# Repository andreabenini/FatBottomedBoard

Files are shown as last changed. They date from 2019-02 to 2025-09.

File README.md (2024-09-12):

# FatBottomedBoard
_Ben's Custom Keyboard. Huge, large &amp; heavy board for everyday work._  
---
_"This is my definitive keyboard I'll use for my daily work"_. This phrase is pretty much the same
every keyboard builder reports and relates to her/his work. I spend most of my time in front of it and
as many others I'd like to customize few things. Project is nearly complete and the keyboard is
working fine but, as many other do, it's much more a work in progress and always improvable where new
features are constantly added. This is not a blog but just a repository where all stable features are
reported, released and shared to the public, hopefully you can contribute to it, pull request or add
features to the project as well.

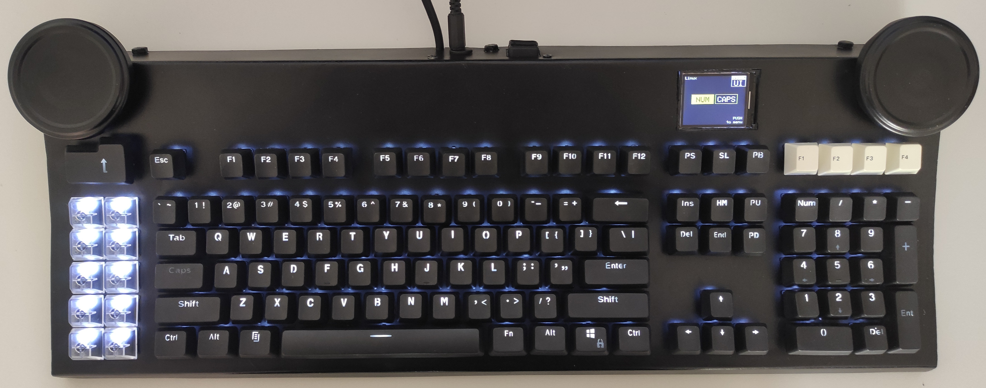
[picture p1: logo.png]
Keyboard overview


---
## Project featured on
- ### [hackaday.com](https://hackaday.com/2020/10/09/fat-bottomed-keebs-you-make-the-clackin-world-go-round/)
- ### [hackster.io](https://www.hackster.io/news/fatbottomedboard-is-a-massive-sun-type-5-style-mechanical-keyboard-for-serious-work-faa62c455731)
- ### [cyberreport.io](https://www.cyberreport.io/news/fat-bottomed-keebs-you-make-the-clackin-world-go-round?article=28913)

---
## Notes on the project
- _"This is my keyboard. There are many like it, but this one is mine."_ 
   ([Cit](https://en.wikipedia.org/wiki/Rifleman%27s_Creed)).
- As written on the name this is _not_ a reduced keyboard like a 60-75% or a compact one. It's a fat,
black, bad ass, heavy & huge board for a big desk, it's not portable and it's not the keyboard you
pickup in a bag with your laptop. It's the kind of keyboard you always leave on your desk with your
trusty mouse and big monitors
- _"I already had some parts lying around"_. Another recurring phrase, but it's true. I dismantled two
broken and acient AT/XT (with mechanical switches) keyboards I already had around and I discovered 
Cherry Black keys inside, it's a real pity to throw them away and that's why I've created this project.
Personal time and these keys (lockdown helped too...) are main factors for the project
- **It has to be cheap.** Cherry keys are quite expensive but with these already sourced parts I've
decided to create a really cheap project without breaking the bank. Approx cost is now ~40$ , even
lower if you already have Teensy boards (like me) and you'd like to manually build something on your
own
- **No special tools required.** I don't have access to 3D printers, CNC or PCB machines so I basically
built it everything from scratch. Manually. I'm not a coachbuilder and some particulars are really
rough, I'm aware of it, but it's my keyboard. If someone would donate me a cnc machined kbd frame
I would be really happy to change that.
- **no kits, it's not _just_ an assembly work. Manually build, assembly, adapt, paint.**
If you're looking for another instructables.com project with some sort of kit purchasable on Amazon
this is not the keyboard for you. Everything here starts from scratch. Leds, keys/keycaps, MCUs and
you manually need to build or add everything else.
[Hardware buildlog](hardware/buildlog/README.md) and each step is
pretty well documented, drop me a note for everything else.
- Full _Metal_. Frame comes from manually carved, drilled, sanded, bended and adapted piece
of 3mm stainless steel. Some paint, a drill, files, a Dremel, nut and bolts... and your time...
- **Sun Type 5 was the best layout ever**. I was a big Sun Microsystems fan before obscurantism and
I think Type5 layout is outstanding. I started the keyboard with that layout in mind and I've added
my personal touch and improvements to that.
---

## Project features
- 119 vintage cherry black keys (1984-1988 period)
- Two rotary encoders with push buttons
- LCD color display for user functions, configuration, builtin macros, games, num/caps, layout switch.
  Screen saver function if inactive after a certain period of time.
- Builtin 1Gb SD card for keeping special macros/combinations(/passwords?)
- Two Teensy++ 2.0 boards inside, serial communication between them, source code provided
    * One dedicated to the keyboard matrix only, no dead keys, 20 Cols x 6 Rows.
      [QMK](https://qmk.fm/) opensource firmware, hooks and custom actions
    * One dedicated to the remaining features: LCD, rotary encoders, SD KeyPass, special macros,
      backlight control, games, layout switch, external configuration
- External 5V power supply so you don't need to rely on poor 500mA from USB host side, common ground,
  full control on backlight (PWM without polling) and USB
- PWM led (white) backlight. NumLock and CapsLock are driven by your host, other keys are manually
  controlled with PWM. Several modes available: Normal / AlwaysON / AlwaysOFF / InverseLock
- Black & Transparent backlight keycaps set
- Builtin 4 port USB switch, two ports are internally used for the Teensy boards, two externally
  available for other devices (phones, headsets, ...). Power consumption depends on your external
  power supply, your're not tied to USB limitations
- US International layout on host side, internally switchable layouts (with a dedicated key) for all
non native english speakers. Starts with a EN-US layout (linux rules on that) but you can type latin
(or non latin) accented letters for your language.
Available layouts: UI: USA International EN-US/std, EN-US/int, IT/std.
Firmware extensible to any language
- Switchable OS (Linux: default, MacOS, Windows) [with a key combination] to enter special chars for
your favorite OS, no need to type unicode stuff (even if it remaps to it internally for some letters).
No keyboard drivers or special layouts are needed on the host side, just US-International on host side
- Two rotary encoders with push buttons. Customizable behavior. Now using: mouse scroll on right side,
password and macro keeper/scroller on left side. In setup mode right encoder is used to navigate menus.
- Builtin GAMES. Two rotary encoders and a small LCD screen ? Pong obviously ! More games coming btw..
  probably Arkanoid and other retro 80s games. There's a lot of space on Teensy++
- Special programs keys. Just like Type5 I prefer to have specific Cut/Copy/Paste keys and few more
  for most frequently used programs (need to map them on your OS)
    - Browser button, the big one below the left rotary encoder. Heavily used. (note: keycap from
    alternative bigass enter in the keyset)
    - Frequently used programs: Terminator, VisualStudioCode. Below browser button
    - Frequently used actions: Undo, Redo, Cut, Copy, Paste, Open, Close, Save
      in the left 10keys island
    - Gnome workspace desktop switch (1,2,3,4) for my taste, use whatever them you'd like.
      These are located below the right rotary encoder
- Play, Record, Custom macros with key combinations on each single key, courtesy of QMK firmware
- Ctrl,Alt,Super keys in this order. Just like MacOS cousins I really hate to have [SUPER] key between
  [Ctrl] and [Alt]. When I press in the middle I can send Ctrl+Alt or Ctrl+Shift+Alt with one finger.
- Special layout because I wanted it so (italian native here...). I don't like dead keys layouts and
  I want to use latin letters (è,é,ò,à,ù). Example: FN+E=è, RALT+E=é. So I still use standard us
  layout without worring too much. Same goes for € sign or other special chars as well.
  I prefer to keep US layout (which I love for sysadmin and programming) and enter additional chars
  from my language too when needed
- Large rotary encoder knobs. I want to use them from the side (just like DAS keyboards) or from the
  top (like a turn table). I did some video editing in the past and I still prefer large knobs. 
  _Those are not real knobs !_ They're just pot of jam lids filled with home made **Oogoo**. To me
  these are way better than traditional mouse wheels
- Software configurable from host side. With a python program you can upload a text file with
  custom macros to the keyboard SD card. With the left knob these macros are visible on the LCD
  display and selectable at will.
---

## Resources
- [BOM (Bill Of Materials)](BOM.md) available and up to date, links, costs and resources
- [Hardware buildlog](hardware/buildlog/README.md)
- Three basic sections
    - **[electronics](electronics)** Kicad schematics, pdf, lcd references and specs
    - **[hardware](hardware)** Frame schematics, credits, resource links and a photo buildlog. Everything is
    documented and photos are available to document the entire process
    - **[software](software)** keyboard (QMK with custom code) firmware and controller firmare (encoders, LCD,
    SD Card). Open source and available to everyone

## To Be Done
- Keycaps are still a work in progress (as every keyboard geek always says). Basic standard keyset
  is fine: looks cool, total black, custom backlight. But newly added keys in my 119 layout (+14
  transparent) are still a work in progress. I've bought transparent keys because
  I'd like to paint them black and carve from the internal to keep backlight led with some
  custom signs. 3D printing tests have not led to the expected results.
- Black paint from the inside and carve transparent keysets
- Transparent keys placed on upper right position (where F1-F4 keys were), need to take a new photo.
- Newly added wood rotary knobs are working fine, need to take a new photo for them as well, see
  current progress in the [buildlog](hardware/buildlog/38.big.knob.jpg)
- Remove the Windows keycap with something else, I don't want it in my keyboard
- Add more games. Arkanoids, maybe Pacman and few more
- Audio capabilities to the Teensy (maybe). When you play Pacman is somewhat important :)
- Some login procedure or something to encrypt internal SD card content, I'm now using it to play
  some macros but I'd like to store passwords as well
---

## Contact me
Mail me, clone the project (but give credits), git pull request and improve the software in any way.
I'm available for consulting or just for sharing ideas with you. Links in my github profile as usual.
I really wish to improve the hardware part as well. A contribution but even few 3D printed parts are
well accepted

<br/><br/><br/>
_Have Fun_  
_Ben_

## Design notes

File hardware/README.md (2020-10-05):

Hardware designs & layouts

---
**Note**
- keyboard-frame.png and poster-*.png files are just the temp result of keyboard-frame.eps, the could safely removed from here if needed
- **posterize.sh** splits `keyboard-frame.png` in pieces (`poster-*.png`) so they can be safely printed with 1:1 scale on common A4/US_Letter sheets
- QMK keyboard firmware builder is way better than TMK counterpart, use it to define wirings and create C defines
  and `KEYMAP()` proper mappings. Later on you might adapt generated code to TMK firmware. Just take a look at
  `kb.h` and `kb.c` generated files.
  **fatbottomedboard.json** was generated from https://kbfirmware.com/, you might use it again and return
  to that site to load configuration and alter it if needed.
  **keyboard-layout.json** was generated from http://www.keyboard-layout-editor.com/, you might use it again and return
  to that site to load configuration and alter it if needed.
  **keyboard-layout.[png|svg]** were generated from http://www.keyboard-layout-editor.com/ along with the json file

**Links**
- Layout editor  
  http://www.keyboard-layout-editor.com/
- Plate & Case builder  
  http://builder.swillkb.com/
- QMK Keyboard firmware builder https://kbfirmware.com/  
- Best guide *ever*, tons of suggestions in the entire process  
  https://www.reddit.com/r/MechanicalKeyboards/comments/4l0p41/guide_detailed_guide_to_making_a_custom_keyboard
- Building a keyboard from scratch (good general intro)  
  https://www.geekabit.nl/projects/building-a-keyboard-from-scratch/
- DIY keyboard collection (or how I became a KB-geek...)  
  nice case mods https://deskthority.net/viewtopic.php?f=7&t=2534&start=
- Firmware from TMK project  
  https://github.com/andreabenini/tmk_keyboard
- How to make a keyboard - The Matrix  
  powerful intro and good electrical documentation for a custom built diy keyboard, not just a ready made kit  
  http://blog.komar.be/how-to-make-a-keyboard-the-matrix/
- Brownfox keyboard, custom made keyboard, steel frame is the only thing maded outside this project  
  https://deskthority.net/viewtopic.php?f=7&t=6050&start=
- Custom made keyboard https://imgur.com/gallery/ba3jK (http://kbfirmware.com/)
- HackADay keyboard's bible  
  https://hackaday.com/tag/keyboard/
- Well explained on each single aspetct (hardware, electronics, software)  
  https://www.facebook.com/notes/wez-furlong/building-a-keyboard/10154070897701787/
- Lots of tips and tricks from this guy  
  https://matt3o.com/
- 3D printing resources  
  https://www.reddit.com/r/MechanicalKeyboards/wiki/3dprinting
- Key modifications  
  https://www.reddit.com/r/MechanicalKeyboards/wiki/key_modifications
- DIY resources from geekhack  
  https://geekhack.org/index.php?topic=69582.0
- Minimal Animal Keyboard  
  This guy did a really good job with its creation, just take a look at **imgur** to see it.  
  I'm also considering his important notes related to backlight  
  https://deskthority.net/viewtopic.php?f=7&t=7615&start=  
  https://deskthority.net/viewtopic.php?f=7&t=7779&start=  
  https://imgur.com/a/sWuH1

**Stabilizers**
- Cherry stabilizers mounting (under the plate)  
  https://www.youtube.com/watch?v=a173Blgfmww
- How To Assemble Cherry PCB Mount Stabilizers  
  https://www.youtube.com/watch?v=u-HYNmtP1Hc
- Cherry plate mounted stabilizers [7u,6.25u,2u]. Cheapest price found, they seems to be quite decent clones, don't know about the quality  
  https://www.aliexpress.com/item/32717878890.html

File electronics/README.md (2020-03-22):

# Keyboard schematics
All circuits have been created with _[Kicad](https://www.kicad-pcb.org/)_,
download and use it if you want to see `.sch` files

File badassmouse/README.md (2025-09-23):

# BadAssMouse (BAM!)
Ben's custom made mouse.  
Thinked, engineered and built as a perfect companion for this awesome keyboard.
Huge footprint but light for fast movements, modeled for covering my right hand entirely.

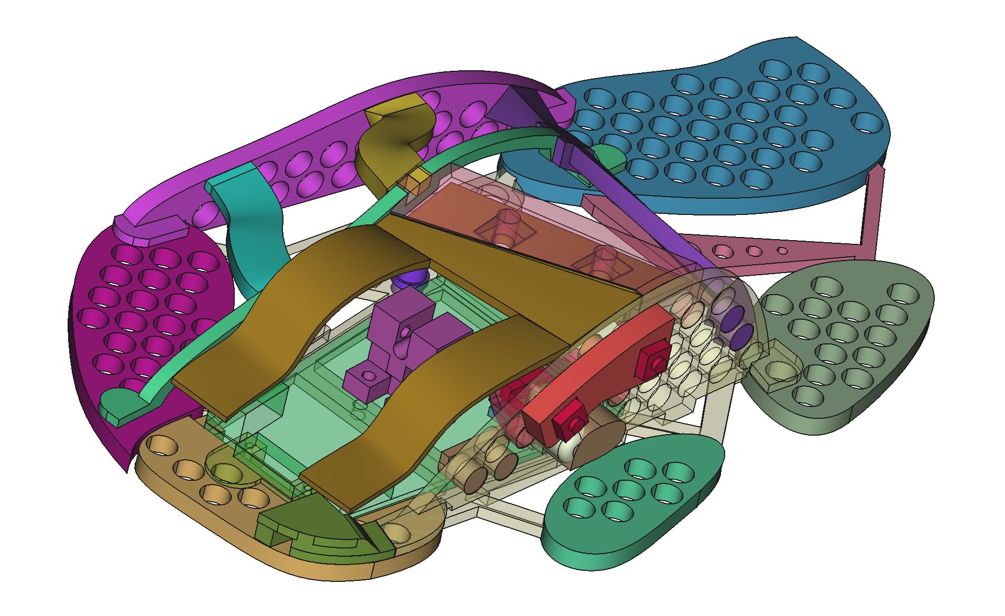
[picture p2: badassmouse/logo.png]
project logo


## Feature List
- lightweight and usable. It's a ~80g device where electronics and spin wheel are around 45g alone, so it's not the lightest mouse in the world as I've seen diy devices below 20g
  but considering consumer's grade devices usually weighting around 170g is not that bad.
- Lightweight & Usable Design: This mouse is engineered to be both lightweight and practical for everyday use
- Ultra-Low Friction Glide  
  Experience a near-frictionless glide thanks to a unique raised design that minimizes surface contact
  - **Minimal Contact:** The mouse body is elevated approximately **3mm** off the desk surface, preventing the main shell from creating any drag
  - **Pinpoint Precision:** It touches the desk on only **very few strategically placed points**, with each contact point having a tiny surface area of just **1 square millimeter**
  - **Built to Last:** Constructed from durable ABS plastic, the frame is reinforced with **4mm thick pillars**. This robust design is the primary reason for its weight,
    but it also guarantees a solid, flex-free body that can withstand heavy use
  - **Effortless Movement:** This design and overall weight drastically reduces friction, allowing the mouse to move with minimal effort and maximum speed, feeling almost as if
   it's floating around
- Reliable, Recycled Internals  
The core of this mouse is built upon proven technology, giving it a reliable and high-performance foundation
  - **Logitech Heart:** The main PCB and all essential electronic components have been carefully transplanted from a classic **Logitech M500** laser mouse
  - **Proven Performance:** This approach leverages the quality and reliability of Logitech's sensor and engineering, ensuring excellent tracking and button response without reinventing the wheel
- Hyper-Fast 'Infinity' Scroll  
One of the most celebrated features of the donor Logitech M500 has been fully integrated into this build: the hyper-fast, dual-mode scroll wheel
  - **Effortless Navigation:** The scroll wheel can be toggled into a free-spinning "infinity" mode. With a single flick, you can coast through thousands of lines in documents, spreadsheets, or web pages instantly
  - **Dual-Mode Precision:** The mouse retains the ability to switch back to a standard, tactile "click-to-click" mode for when precision and line-by-line control are needed
  - **A Signature Feature:** This powerful and satisfying function is a direct result of using the M500's internals, bringing a premium, productivity-enhancing feature to a unique custom body
- Dedicated Thumb Button (Middle Click)  
To improve ergonomics and functionality, a custom third mouse button has been added, accessible to the thumb
  - **Ergonomic Placement:** This new button is positioned laterally on the side of the mouse, offering a much more comfortable way to trigger a middle click without altering your grip
  - **Enhanced Functionality:** While the traditional middle click obtained by pressing the scroll wheel is still available, having a 
    **dedicated thumb button** is far superior for actions in 3D modeling software (GIMP, FreeCAD, Blender, Cura, ...)
  - **User Choice:** This design provides two distinct ways to perform a middle click, offering flexibility and a better user experience overall.
- Horizontal Tilt-Wheel Scrolling  
Another powerful feature inherited from the Logitech M500 internals is the tilt-wheel functionality
  - **Side-to-Side Scrolling:** The scroll wheel can be tilted left and right, providing seamless **horizontal scrolling**
  - **Productivity Boost:** This is incredibly useful for navigating wide spreadsheets, timelines in video editing software, or large images without having to use horizontal scroll bars
- Hyper-Personalized Ergonomics: Function Over Form  
Let's be honest: this mouse wasn't designed to win any beauty contests (it's ugly as hell)
  - **Custom-Molded Fit:** The external shell is unapologetically functional, sculpted specifically to the unique contours of **my** hand. It may look ugly as hell, 
    but every curve and indentation is intentional, designed for a perfect, strain-free grip
  - **Comfort is King:** While its looks are unconventional, the result is a level of comfort and control that mass-produced mice can't possibly match.
    It's built for endurance and a seamless connection between hand and cursor.
  - **Truly One of a Kind:** This is the core philosophy of the project. It's not just *a* mouse; it is quite literally **'my mouse'**. 
    The design is a unique expression of personal ergonomics, creating a tool that is perfectly tailored to its one and only user.
- Modular, LEGO-like Construction  
The entire mouse is designed with a modular, "LEGO-like" philosophy, allowing for endless iteration and customization
  - **Snap-Fit Assembly:** All the structural parts of the shell are designed to connect using precise snaps. This allows for rapid, tool-less assembly and disassembly 
    during the design and testing phases.
  -  **Iterative Design:** This system makes it incredibly easy to experiment with different shapes and component layouts. Once I'm happy with the form, a few drops of
    cyanoacrylate glue are used to make the connections permanent and rigid.
  - **Infinitely Reshapeable:** The core principle is flexibility. The mouse isn't a final, static object but a platform that can be easily broken down, modified, and
    rebuilt in a completely new form whenever desired.
- 3D Print Files and design available  
All the 3D models required to print your own version of this mouse are available in this repository
  - **Files Available:** You can find all the `.stl` design files ready for slicing in this directory
  - **Recommended Material:** ABS is highly recommended to match the sturdiness and durability of the original design. PLA can be used, but may be more brittle

## Pictures
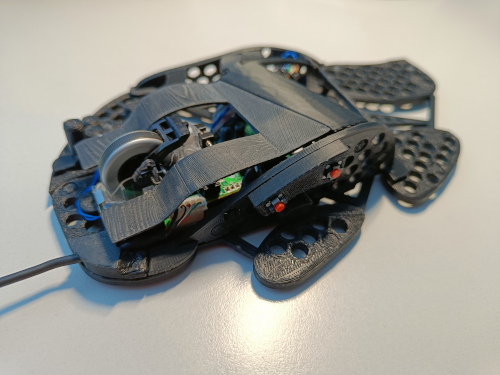
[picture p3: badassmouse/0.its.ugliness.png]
The guy, in real life
  
Its ugliness, in real life

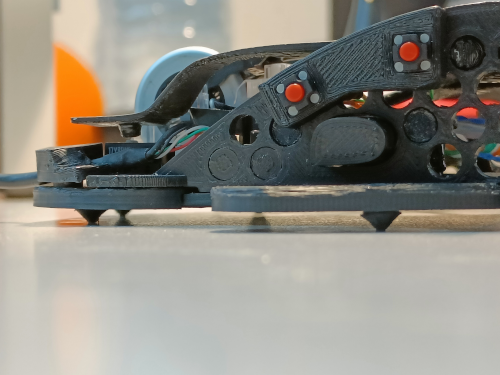
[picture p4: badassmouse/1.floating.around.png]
Floating in style
  
Floating on the desk

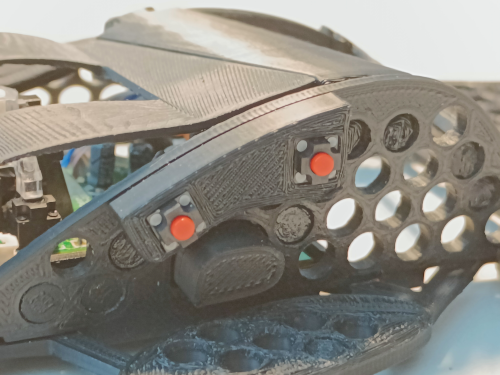
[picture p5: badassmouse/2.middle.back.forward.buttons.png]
Thumb button
  
middle/thumb button, back and forward buttons (silent switches, fast, low profile, low stroke)

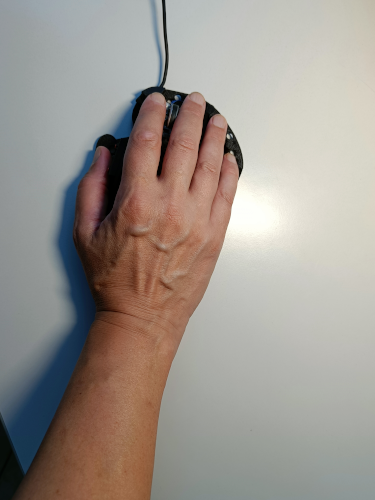
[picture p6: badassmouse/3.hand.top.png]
my mouse, my hand
  
Mouse covers the entire hand up to the wrist

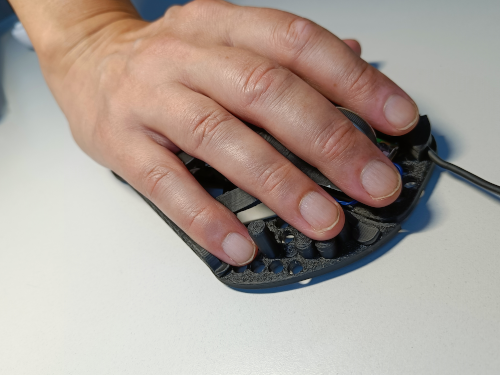
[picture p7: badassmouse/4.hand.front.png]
fingers view
  
Every finger is differently raised for ergonomics

## Support the Project
If you've enjoyed this project and would like to support its future development, thank you! Every little bit helps and is incredibly motivating
- **Fund the Next Version:** The dream is to create an even lighter and stronger V2 using **carbon fiber filament**. If you'd like to help make that a reality,
you can **buy me a spool of filament directly** or contribute towards the cost
- **Contribute Financially:** A small donation to help cover prototyping costs is always welcome. You can do so via [**PayPal**](paypal.me/bendonations)
- **Share the Project:** If you can't contribute financially, no problem at all! A star on the repository or giving project attribution when you share or use
the design is a fantastic and highly valued way to show your support

## Changelog

- **Revision 4**. Instead of modeling on a fully fledged mouse from internet this new version has been recreated
  totally from scratch and it's based on the shape of my hand only.    Weight and minimal points of contact with
  the surface are also key factors of this new design.  Electronics from M500 because I still have some of them.
- **Revision 3**. Cura sliced version, buttons in places, a lot of inner working on buttons thickness,
    internal palm support still in progress, external is fine but internal buttons shapes are not there yet.
- **Revision 2**. Lightly adapted print with better accomodations for the whole hand, fits well on my right hand
- **Revision 1**. First draft, 3d printed without buttons with overall shape to understand capabilities.

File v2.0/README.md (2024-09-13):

# V2.0
Build in progress, this will replace current version but at the moment it's still an experiment

- new project version is under construction
- Testing new CherryMX switches
- Testing new single key PCB
- BOM is defining while doing it
- No software (yet)
- No electronics (yet)
- 3d model not defined (yet)

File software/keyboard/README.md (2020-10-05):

# Firmware mod
Firmware for FatBottomedBoard

## Setup
#### Software installation
```sh
# or use your favorite package manager to get those packages
sudo pacman -S arm-none-eabi-gcc arm-none-eabi-newlib
```
#### Project setup
```sh
# cloning github project
git clone https://github.com/qmk/qmk_firmware
# Entering proper directory
cd qmk_firmware
# Creating submodule to start your own environment
make git-submodule
# Try to compile a basic example (optional)
make handwired/onekey/teensy_32:default
# Clean that basic example
make clean
```
#### Copy project configuration
```sh
# Add current configuration to qmk project
cd qmk_firmare/keyboards
ln -s ../../config/fatbottomedboard .
```

## Keyboard Manual
[This is up to date keyboard manual](manual.md) with keys, macros, layouts and current configuration.  
Complete keyboard layout is available in the [hardware section](../../hardware)

## Links 
- Hints on classics layouts http://www.quadibloc.com/comp/kyb0301.htm  
- QMK Keyboard firmware builder https://kbfirmware.com/  
- QMK Cheat sheet https://jayliu50.github.io/qmk-cheatsheet/
- List of unicode characters https://en.wikipedia.org/wiki/List_of_Unicode_characters

## Notes
QMK keyboard firmware builder is way better than TMK counterpart, use it to define wirings and create C defines
and `KEYMAP()` proper mappings. ~~Later on you might adapt generated code to TMK firmware.~~ Just take a look at
`kb.h` and `kb.c` generated files.  
**fatbottomedboard.json** was generated from https://kbfirmware.com/, you might use it again and return
to that site to load configuration and alter it if needed.  
[QMK](https://qmk.fm/) firmware was chosen for the project due to its cool features and good
documentation, reading docs and applying those features in a couple of hours is preferred to hacking
for weeks with an uncertain result and _(maybe)_ a 5% performance increase. **Even more:** user hooks
for custom code (here used for serial comm) with plain avr-gcc **C** code is awesome.

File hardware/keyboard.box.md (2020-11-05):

### FatBottomedBoard
# Keyboard Box
### Self locking box
|Dimensions|Internal|&nbsp;&nbsp;&nbsp;&nbsp;&nbsp;&nbsp;|External|
|---|--:|---|--:|
|_Length_|**55 cm**||**~68 cm**|
|_Width_ |**22 cm**||**~88.5 cm**|
|_Height_|**8.5 cm**||_paper ~0.4 cm_|

Keyboard width: 51.5 cm  
Knob ledge (each) ~1 cm (with 6.5cm knobs)  

Schematics  
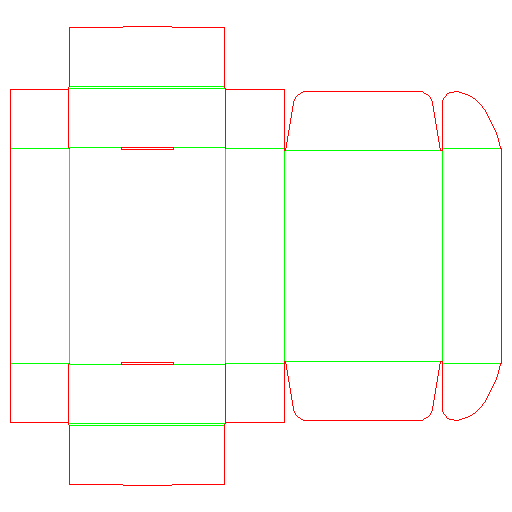
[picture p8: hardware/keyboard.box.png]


Box Preview  
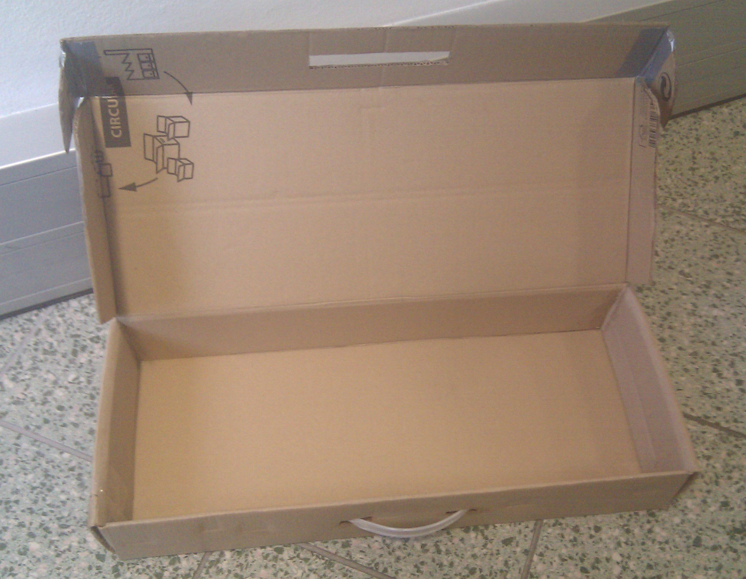
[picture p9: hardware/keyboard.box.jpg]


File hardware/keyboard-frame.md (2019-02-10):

# Settings
These are the settings for the frame builder (http://builder.swillkb.com/)

- Switch type: **MX {_t:1}**
- Stabilizer Type: **Cherry Only {_s:2}**
- Case Type: **Sandwich**
- USB cutout: **off**
- Mount holes: *8, 3, 10*
- Edge padding: **on (Top 35, Left 15, Right 15, Bottom 10)**
- Plate corners: **off**
- Custom Polygons: **on**
  * Rectangle (switch layer)
    - **width: 516, height: 40, centers: [0,-y-21], [0,0]**
  * Rectangle (switch layer)
    - **width: 516, height: 20, centers: [0,y+11], [0,0]**
- Kerf: **off**
- Key unit size: **off**
- Line color: **off**
- Line height: **off**

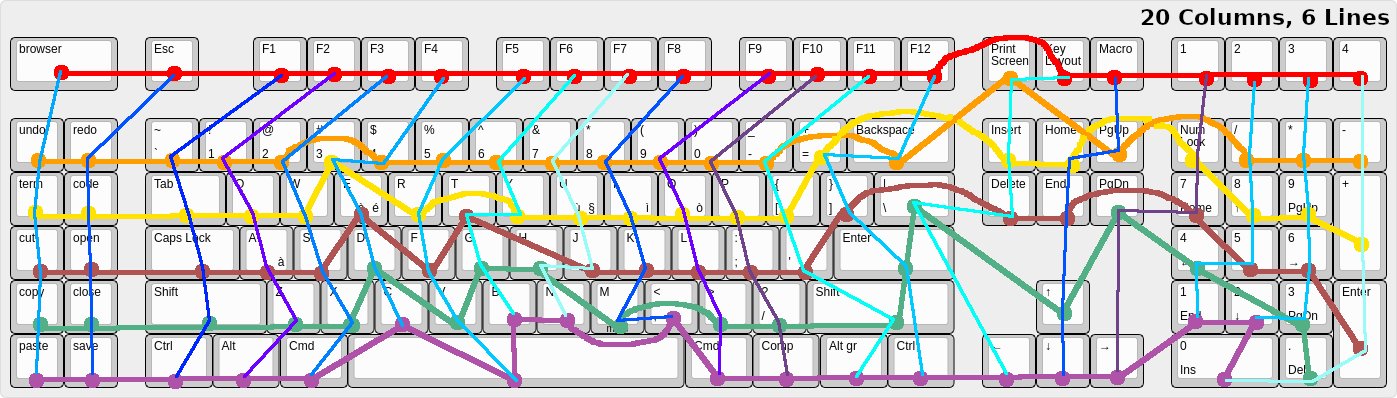
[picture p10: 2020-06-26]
hardware/keyboard-matrix.png

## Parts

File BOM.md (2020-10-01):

# Hardware
Buildlog and materials provided from the hardware section
- 50x50cm, 2mm stainless steel sheet. Got it from a surplus sale in a local hardware store. It's a poor quality and 2nd choice
  material, thin coated with cheap black paint, poorly finished. The only thing I like of it is the stainless, 2mm is fine because
  is not too thin or thick, good enough for keys and stabs mounts. Coating has to be brushed or replaced with something else.
  Really cheap part from a surplus sale cost: 5.00 €
- DIY Oogoo. Used as a filler for the Keyboard sides. 35% Corn Starch (Maizena), 60% Transparent Silicone, 4% Neoprene glue, 1%
  Laser printer black toner (from an used cartridge). Basic recipe from
  [Instructables](https://www.instructables.com/id/How-To-Make-Your-Own-Sugru-Substitute/)
  but hardened with the Neoprene glue. Mix and apply it quickly before it dries.
- [Mechanical Keyboard Plate Mounted Stabilizers](
https://www.banggood.com/Mechanical-Keyboard-Plate-Mounted-Stabilizer-6_25u-Modifier-Key-Spacebar-For-104108Keys-p-1249526.html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
  )
  #2 items (for backup and tests), I'll use most of them due to my extended keyboard. #2 x 8.77$
- Black spray paint, matte black (**RAL 9005**).  Car Wax. I already had them but you can purchase these in your local hardware
  store easily.
- 119 Cherry Black switches. Got them for free after dismantling two acient AT/XT keyboards. These are vintage Cherry Black buttons 
  from the 80s. Donor keyboards were reporting 1988 as the production date so these are original Black keys from the 1984-88 period.
- PBT English Language 108 Keyscaps Keys for Cherry MX Mechanical Keyboard Key Cap Switches, black matte (because it's cool).
  These are fairly good keycaps even if the price is bottom low. Nothing fancy but price is good and quality seems fine, time will
  tell how long they'll last.
  Just got [these keycaps](https://www.aliexpress.com/item/32902062981.html?spm=a2g0s.9042311.0.0.2c404c4dDWLgtp) from Ali for only 9.99
  but there're even cheaper ones, pick up your favorite color or theme, I was looking for black keycaps with backlight capabilities.
- _(R4)_ 10Pcs Transparent ABS Keycaps Mechanical keyboard Keycaps Matte Backlit Keycaps For Cherry Switch. Standard keycaps set
  (104-108) does not cover my keyboard schema and I need something more to keep up with my 119 switches. I don't want to paint them
  externally or ruin the touch so I bought them for some tests, pretty cheap too (**~2$**) so I can make a lot of tries. If results
  are decent I can even buy R1..R4 keys to match current switches.  
  I've found these https://www.aliexpress.com/item/4000645380162.html?spm=a2g0s.9042311.0.0.1dc24c4dvSdjEP but other alternatives
  are accepted as well, drop me a note or few hints on this.

# Electronics
Schematics available in the same dir, materials required are listed below:
- #2 Teensy 2.0++ USB AVR Development Board. Builtin USB controller, 5V version, Arduino toolchain and software. Original or cloned
  versions are both fine, price range on **5~10 €** from usual far east resellers, for example [this one](
      https://www.aliexpress.com/item/4000431099525.html?spm=a2g0s.9042311.0.0.5e3c4c4djyiYr1
  ) but there're cheaper alternatives on DX, Banggood and sites like that.  
  One for the controller, one for the keyboard firmware.
- 1.8" TFT display module, 128x160 8PIN TFT LCD, ST7735S Controller Drive 8/16 Bit SPI For Arduino Micro with SD.
  Ultra cheap and quite small head up like display for various keyboard functions, connected to the ATmega32U4 for
  custom configurations, password keeper and fancy setup. Easily available across the **2~3 €** price range, just like
  [this one](
      https://www.aliexpress.com/item/32906859151.html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
  )
- 119 1N4148 Diodes for the keys
- TIP112 NPN Darlington Transistor. 60V 2A. Because I already had it around but you can use whatever Darlington you've, better if it
  can handle more than 2A even if I won't use nominal 20mA on LEDs, they're really bright with just 10mA so this Darlington is fine
  as well.
- 1 1K&#8486; resistor for the Darlington base
- 117 470&#8486; resistors (backlight LEDs)
- 2 330&#8486; resistors (numlock and capslock leds), these are controlled directly from the Teensy++ not from the Darlington
- Spare resistors for the LCD display: 6x1K&#8486;, 1x330&#8486;, 1x100&#8486;
- Heat shrink tubing, wirings get complicated if you sum backlight wirings (one resistor, one key) and common keyboard matrix (one diode
  for each key). See buildlog for details.  You'd better insulate cables when you use your soldering iron. Alternatively you might use
  enameled wire but when you weld diodes you still have some tin to insulate

# Software
Everything is open source from this repository, no external deps required. You can pickup ready made _.hex_ binary files or compile them
on your own.  
Use GitHub pull requests, issues and comments here or on chat for your getting in touch.

&nbsp;
### NOTE
---
BOM defined contains all materials used for the making, prices are indicative and many components are not planned from scratch,
project is mainly based on what I've around.  
I can keep it cheap because it's based on already purchased materials. Project started because I've scavenged vintage cherry black
switches from old devices. Personal time and manual skills can keep the price low but this might cost you as well 
_(can you measure it ?)_

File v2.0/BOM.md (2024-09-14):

# Hardware
Buildlog and materials provided from the hardware section
- Mechanical Keyboard Plate Mounted Stabilizers, from version 1 of this project
- Black spray paint, matte black (**RAL 9005**).  Car Wax. I already had them but you can purchase them in your local hardware
  store easily.
- PBT English Language 108 Keyscaps Keys for Cherry MX Mechanical Keyboard keycap switches, black matte (because it's cool).
  Recycled them from version 1 of this project, original cost was around 9.99. There's no difference between standard Cherry keycaps
  and low profile ones, they usually fit well.
- _(R4)_ 10Pcs Transparent ABS Keycaps Mechanical keyboard Keycaps Matte Backlit Keycaps For Cherry Switch. Standard keycaps set
  (104-108) does not cover my keyboard schema and I need something more to keep up with my 120 switches. I don't want to paint them
  externally or ruin the touch. mostly recycled from version 1 too.

# Electronics
Schematics available in the same dir, materials required are listed below:
- MxLEDBit Single Switch PCB, MX/Choc/Hot Swap Socket, Cherry MX version, Led ready, 4x25pcs, ~4.90E. (each).
  That's my biggest departure from my previous fully handmade wired project, these boards are a timesaver, handy, thin, cheap and
  provide better results. They also save you a huge amount of time while wiring. 1U Amoeba pcb boards are totally fine but this one
  is cheaper to purchase in the EU (no customs). You can get discounts and a competitive price from usual PCB manufacturers even if
  it seems to be the best bet for my money here. They can perfectly fit with all Cherry MX switches including low profile ones.  
  [Single Switch PCB](https://keycapsss.com/keyboard-parts/pcbs/173/mxledbit-single-switch-pcb-mx-choc-hot-swap-socket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)
- Original Cherry MX low profile rgb Red Switch, 120pcs, ~50E. (various discounts might apply based on the season).  
  This is obviously where most of the budget goes, discount and various prices might apply and if you have a cheaper alternative
  open an issue or let me know as a comment.  
  Before starting the flame on MX flavors I'd like to report I'm a heavy hitter and always been a cherry black fan. I also used
  cherry brown for a while but these low profiles are amazing and I finally decided to use Reds, on low profile ones the bump on
  brown does not really makes any sense to me.  
  [Original Cherry MX low profile RED](https://www.aliexpress.com/item/1005007533369880.html?spm=a2g0o.order_list.order_list_main.15.46df1802PQbq6Z)
- SMD diode, 1N4148W, SOD123 package, 2x100pcs, ~2.50E (from timely aliexpress discounts).  
  Common 1n4148 are fine too, In my case I've decided to use the SOD123 package to minimize space, through hole diodes are good as well.  
  [1N4148 Diodes](https://www.aliexpress.com/item/1005005707644429.html?spm=a2g0o.order_list.order_list_main.10.46df1802PQbq6Z)
- GTBL SK6812 SMD MINI-E RGB LED Chip Individually Addressable Full Color DC 5V, 2x100pcs, ~7.20E. (discounted in a sale on AliExpress).
  These are optional, I have plenty of high intensity 3mm white leds and there's no need to purchase these SMDs if you are considering
  manually wiring. BTW these are thinner and they perfectly fit inside low profile cherry mx switches. They are inexpensive and
  a nicely added value if you are considering a low profile layout.  
  [SK6812 SMD RGB Leds](https://www.aliexpress.com/item/1005003056797785.html?spm=a2g0o.order_list.order_list_main.5.46df1802PQbq6Z)
- Teensy 2.0++ USB AVR Development Board. Builtin USB controller, 5V version, Arduino toolchain and software. Originals or cloned
  versions are both fine, price range from usual far east resellers. This comes free from version 1 of this project. I'm using
  teensy 2++ because they provide a lot of inputs for a huge matrix like mine (120 keys). QMK keyboard firmware with some special
  mods to support my fancy remapping and add communication features to exchange data between these two MCUs

#### To be defined
    - 1.8" TFT display module, 128x160 8PIN TFT LCD, ST7735S Controller Drive 8/16 Bit SPI For Arduino Micro with SD.
      Ultra cheap and quite small head up like display for various keyboard functions, connected to the ATmega32U4 for
      custom configurations, password keeper and fancy setup. Easily available across the **2~3 €** price range
    - 1 1K&#8486; resistor for the Darlington base
    - Spare resistors for the LCD display: 6x1K&#8486;, 1x330&#8486;, 1x100&#8486;
    - Heat shrink tubing, you'd better insulate cables when you use your soldering iron

# Software
Everything is open source from this repository, no external deps required. You can pickup ready made _.hex_ binary files or compile them
on your own. Use GitHub pull requests, issues and comments here or on chat for your getting in touch.

&nbsp;
### NOTE
---
BOM defined contains all materials used for the making, prices are indicative and many components were not planned from scratch,
project is mainly based on what I've around.

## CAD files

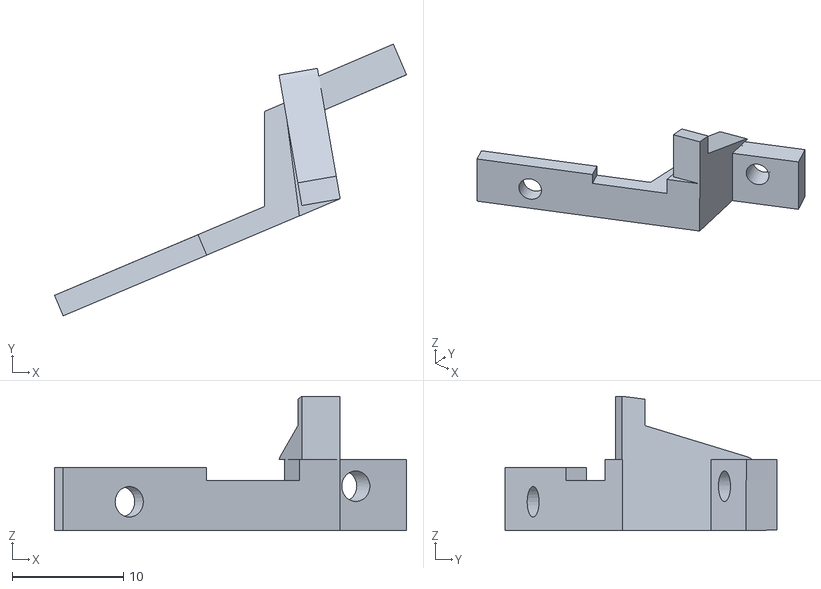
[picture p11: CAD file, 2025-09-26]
badassmouse/bam-underbridge blocker.stl
31.6 x 24.4 x 12.1

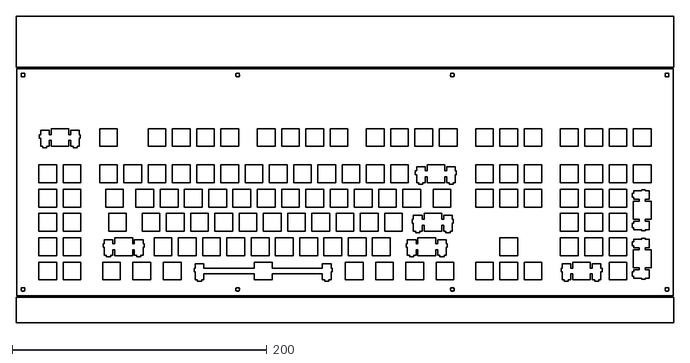
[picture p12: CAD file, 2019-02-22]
hardware/keyboard-frame.dxf
516.0 x 240.4

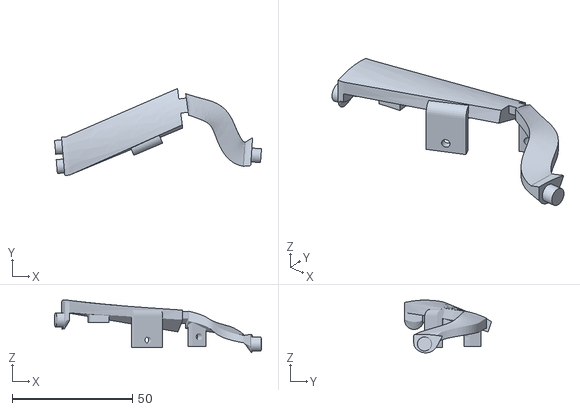
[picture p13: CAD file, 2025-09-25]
badassmouse/bam-partition pinky right 2.stl
86.1 x 36.2 x 21.9

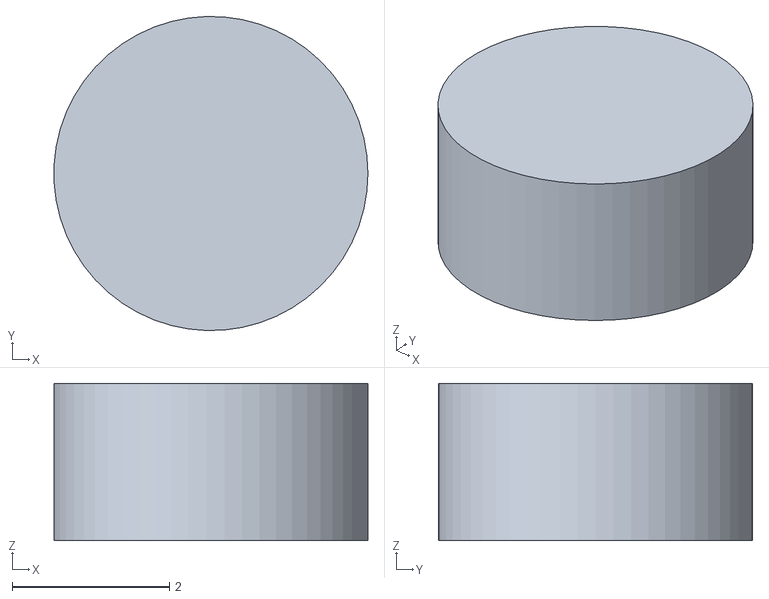
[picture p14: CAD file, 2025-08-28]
badassmouse/bam-mouse button thickness.stl
4.00 x 4.00 x 2.00

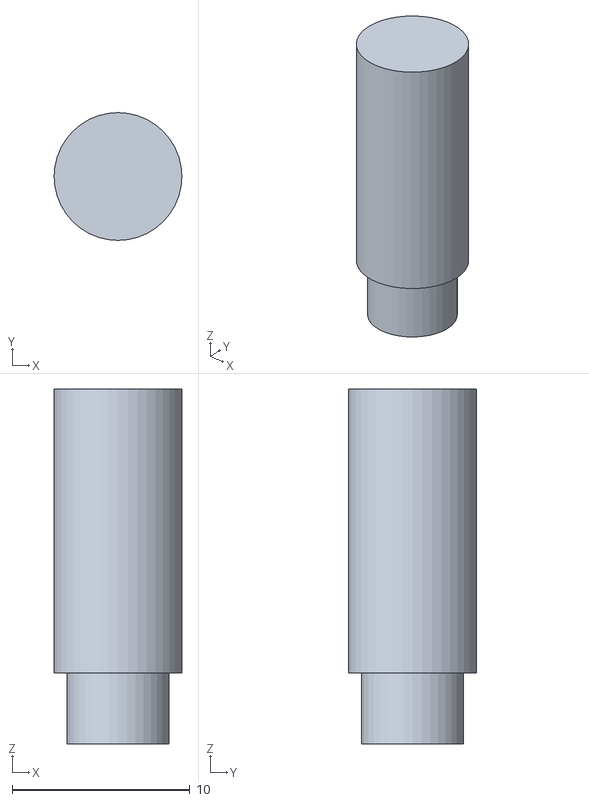
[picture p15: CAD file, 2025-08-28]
badassmouse/bam-Ring holder top.stl
7.20 x 7.20 x 20.0

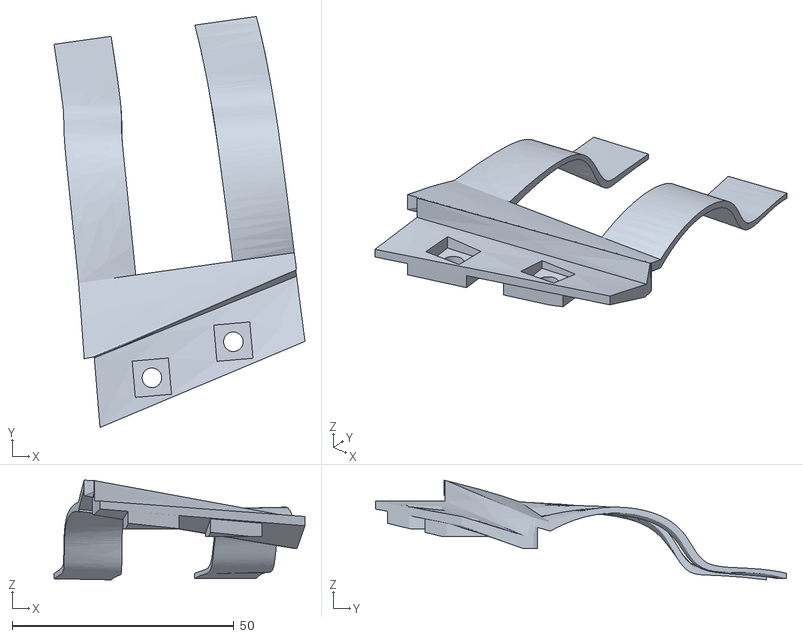
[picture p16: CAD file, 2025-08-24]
badassmouse/bam-mouse buttons.stl
56.6 x 92.6 x 22.5

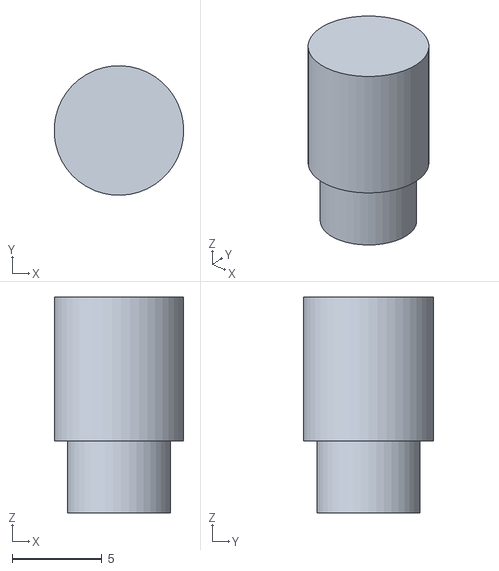
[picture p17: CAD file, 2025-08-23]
badassmouse/bam-Ring holder.stl
7.19 x 7.20 x 12.0

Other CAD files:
electronics/SKU676781/51 test procedure/Comprehensive test (requires more than 16K ROM microcontroller)/Comprehensive test (requires more than 16K ROM microcontroller)/main.OBJ
electronics/SKU676781/51 test procedure/Basic brush test/main.OBJ
electronics/SKU676781/51 test procedure/Basic brush test/touch.obj
electronics/SKU676781/51 test procedure/Comprehensive test (requires more than 16K ROM microcontroller)/Comprehensive test (requires more than 16K ROM microcontroller)/font.obj
electronics/SKU676781/51 test procedure/Basic brush test/LCD.obj
electronics/SKU676781/51 test procedure/Comprehensive test (requires more than 16K ROM microcontroller)/Comprehensive test (requires more than 16K ROM microcontroller)/sys.obj
electronics/SKU676781/51 test procedure/Basic brush test/font.obj
electronics/SKU676781/51 test procedure/Basic brush test/STARTUP.OBJ
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

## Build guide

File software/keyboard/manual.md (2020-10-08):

# Keyboard manual _(BABE)_

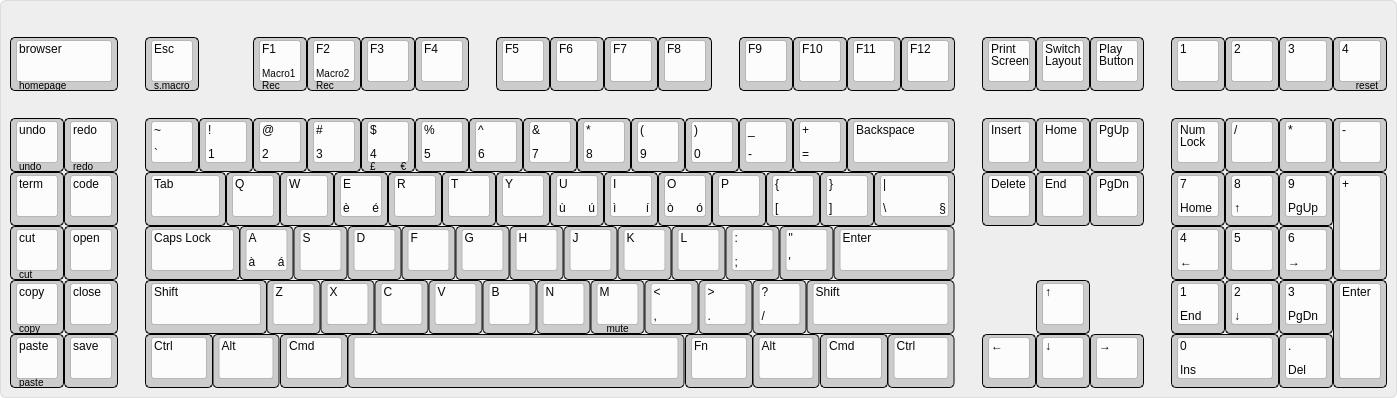
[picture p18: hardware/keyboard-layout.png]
Keyboard layout

Here you can see the complete keyboard with silk-screen keys

---

## Host configuration

Just _one_ simple rule: **SELECT US-English Keyboard Layout. That's it, no more, no less.**  

There's no need to use US-International, language packs or additional layouts on the host side.  
Each operating system has its own ways to enter latin characters (á,é,í,ó,ú, ...), I've tried to
skip dead keys layout, US International sounds cool but it's a mess if you'd like to enter ',",`,...
Windows particularly sucks on this aspect and many users created
special keyboard layouts to override US-Intl behavior with dead keys, there's no need for that.

## Special inputs characters
| Combination | Result | Example or Notes|
|- |- |-|
| _Special Characters_ |||
| **\<FN>**+**_\<letter>_** | [**`**] Grave accent letter | FN+e = è |
| **\<ALT>**+**_\<letter>_** | [**´**] Acute accent letter | ALT+e = é |
| **\<ALT>**+**_<4>_** | [**€**] Euro sign | _where **$** sign is reported_ |
| **\<FN>**+**_<4>_** | [**£**] Pount sign | _where **$** sign is reported_ |
| **\<FN>+\<\\>** | § | § |
| _Editing Functions_ |||
| **\<UNDO>** | Ctrl+Z | Generic undo key |
| **\<REDO>** | Ctrl+Y | Redo with Ctrl+Y (vscode) |
| **\<FN>+\<REDO>** | Ctrl+Shift+Z | Redo with Ctrl+Shift+Z (eclipse) |
| **\<CUT>** | \<Ctrl>+\<X> | Cut |
| **\<FN>+\<CUT>** | \<Shift>+\<Del> | _cut_  _(classic)_|
| **\<COPY>** | \<Ctrl>+\<C> | Copy |
| **\<FN>+\<COPY>** | \<Ctrl>+\<Insert> | _copy_ _(classic)_|
| **\<PASTE>** | \<Ctrl>+\<V> | Paste |
| **\<FN>+\<PASTE>** | \<Shift>+\<Insert> | _paste_ _(classic)_|
| _OS Features_ |||
| **\<Browser>** | Start chrome browser | Mapped to LSFT(KC_F20) on OS  |
| **\<FN>+\<Browser>** | Browser Home (Windows) | _#define KC_WWW_HOME_  |
| **\<FN>+\<M>** | Volume mute | _#define KC__MUTE_ |
| **\<SwitchLayout>** | Toggle keyboard layouts | **EN**:US English, **IT**:Italian, **UI**:US International|
| **\<FN>+\<SwitchLayout>** | Toggle OS | Toggle OS (Linux, MacOS, Windows) |
| _Macro Functions_|||
| **\<PlayButton>** | Layer for macro input | Toggle layer for playing macros |
| **\<FN>+\<F1>** | Record MACRO1 | Start recording MACRO1 |
| **\<FN>+\<F2>** | Record MACRO2 | Start recording MACRO2 |
| **\<FN>+\<ESC>** | Stop recording macro | Stop recording previously started macro (if any)|
| **\<PlayButton>+\<F1>** | Play recorded MACRO1 | Execute recorded MACRO1 |
| **\<PlayButton>+\<F2>** | Play recorded MACRO2 | Execute recorded MACRO2 |
| _Firmware Functions_|||
| **\<FN>+\<WS4>** | Reset keyboard | boot loader for firmware upgrade |
**NOTES:**
- **MACRO1**, **MACRO2** can be created/modified at runtime but are volatile, they're lost when
keyboard is turned off

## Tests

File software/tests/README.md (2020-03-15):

All of the Pro Micro's I/O and power pins are broken out to two, parallel headers. 
Some pins are for power input or output, other pins are dedicated I/O pins. 
Further, the I/O pins can have special abilities, like analog input. 
Here's a map of which pin is where, and what special hardware functions it may have:

# Pro Micro Pinout
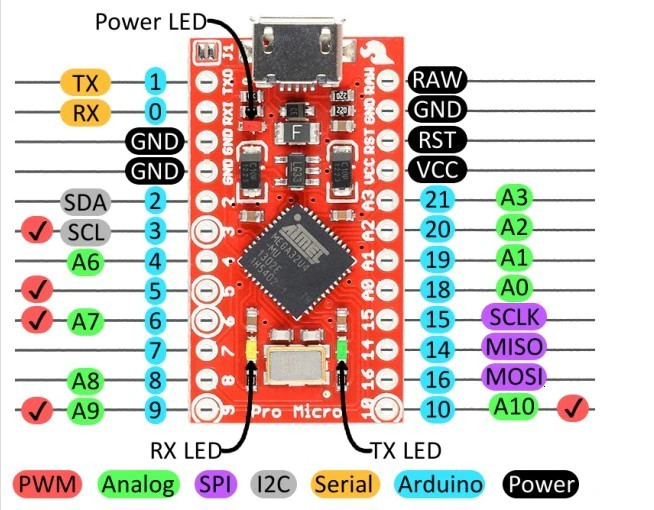
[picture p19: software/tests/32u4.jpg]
preview
  
Delving a little further into which pins do what...

## Power Pins
There are a variety of power and power-related nets broken out:

- RAW is the unregulated voltage input for the Pro Micro.
If the board is powered via USB, the voltage at this pin will be about 4.8V (USB's 5V minus a schottkey diode drop).
On the other hand, if the board is powered externally, through this pin, the applied voltage can be up to 12V.
- VCC is the voltage supplied to the on-board ATmega32U4.
This voltage will depend on whether you're using a 3.3V/8MHz Pro Micro or a 5V/16MHz version,
it'll be either 3.3V or 5V respectively. This voltage is regulated by the voltage applied to the RAW pin.
If the board is powered through the 'RAW' pin (or USB), this pin can be used as an output to supply other devices.
- RST can be used to restart the Pro Micro. This pin is pulled high by a 10kOhm; resistor on the board, 
and is active-low, so it must be connected to ground to initiate a reset. 
The Pro Micro will remain "off" until the reset line is pulled back to high.
- GND, of course, is the common, ground voltage (0V reference) for the system.

## I/O Pins
The Pro Micro's I/O pins -- 18 in all -- are multi-talented.
Every pin can be used as a digital input or output, for blinking LEDs or reading button presses.
These pins are referenced in the Arduino IDE via an integer value between 0 and 21.
(The A0-A3 pins can be referenced digitally using either their analog or digital pin number).

Nine pins feature analog to digital converters (ADCs) and can be used as analog inputs. 
These are useful for reading potentiometers or other analog devices using the analogRead([pin]) function.

There are five pins with pulse width modulation (PWM) functionality, 
which allows for a form of analog output using the analogWrite([pin], [value]) function. 
These pins are indicated on-board with a faint, white circle around them.

There are hardware UART (serial), I2C, and SPI pins available as well. 
These can be used to interface with digital devices like serial LCDs, XBees, IMUs, and other serial sensors.

The Pro Micro has five external interrupts, which allow you to instantly trigger a function when a 
pin goes either high or low (or both). If you attach an interrupt to an interrupt-enabled pin, you'll need 
to know the specific interrupt that pin triggers: pin 3 maps to interrupt 0 (INT0), pin 2 is interrupt 1 (INT1), 
pin 0 is interrupt 2 (INT2), pin 1 is interrupt 3 (INT3), and pin 7 is interrupt 4 (INT6).

## On-Board LEDs
There are three LEDs on the Pro Micro. One red LED indicates whether power is present.

The other two LEDs help indicate when data is transferring over USB. 
A yellow LED represents USB data coming into (RX) the the Pro Micro, 
and a green LED indicates USB data going out (TX).

## 3.3V or 5V? 8MHz or 16MHz?
Pro Micros come in two flavors, which vary by system voltage and operating frequency. 
The standard 5V Pro Micro runs at 16MHz, and is very comparable to an Arduino Leonardo, 
while the 3.3V version of the Pro Micro runs at half the speed 
(to remain in the safe operating zone at the lower voltage) -- 8MHz.

The operating voltage of your Pro Micro determines the maximum allowable voltage on any of the I/O pins.
For example, if you have a 3.3V Pro Micro, don't interface it with something that outputs 5V.

Don't forget which version you have! We'll need to differentiate between the two when we get to
uploading code in Arduino. If you're not sure which version you have, check the back corner of the board.
One of two boxes should be checked to indicate the operating voltage.

## How to Power the Pro Micro
As the Pro Micro's main feature is its innate USB functionality, the most common way to power it is via USB.
In this setup, a 5V Pro Micro will be powered directly from the USB bus and a 3.3V Pro Micro will regulate
the 5V supply coming in from USB down. The other end of the USB cable can be connected to either a computer,
USB hub, or a USB wall adapter, which can (in most cases) provide more power.

Alternatively, if your Pro Micro is living out in the wild, out of reach of USB cables, 
it can be powered through either the 'RAW' or 'VCC' pins. A supply going into the 'RAW' pin will be regulated 
down to the correct operating voltage (5V or 3.3V). To be safe, it shouldn't be any higher than 12V, and it 
should be at least 1V more than the Pro Micro's operating voltage (e.g. >6V for a 5V Pro Micro).

If you power the Pro Micro through the 'VCC' pin, keep in mind that this signal is unregulated.
Only use this if you have a clean, regulated 3.3V or 5V supply to connect to it.

How, exactly, you power your project is up to you and the demands of your project. 
If you're making something battery powered, you may want to opt for the 3.3V Pro Micro, which could be powered
by a LiPo battery or a couple alkalines.

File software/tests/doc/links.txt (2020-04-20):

LCD TFT Display
https://randomnerdtutorials.com/guide-to-1-8-tft-display-with-arduino/
https://www.hackster.io/electropeak/ultimate-beginner-s-guide-to-run-tft-lcd-displays-by-arduino-081006
https://electropeak.com/learn/absolute-beginners-guide-to-tft-lcd-displays-by-arduino/
http://acoptex.com/project/263/basics-project-054a-18-spi-tft-lcd-128x160-module-and-flickering-streaks-at-acoptexcom/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

Rotary Encoders
https://howtomechatronics.com/tutorials/arduino/rotary-encoder-works-use-arduino/
https://www.brainy-bits.com/arduino-rotary-encoder-ky-040/  (debouncing and inaccuracy sw fixes)

Buttons
https://create.arduino.cc/projecthub/muhammad-aqib/arduino-button-tutorial-using-arduino-digitalread-function-08adb5

Keyboard-Mouse
https://www.arduino.cc/en/Tutorial/KeyboardMessage
https://www.sparkfun.com/tutorials/337

Software [PC]
https://github.com/signal11/hidapi          [hidapi lib]
https://github.com/trezor/cython-hidapi     [Python import]

Software [Arduino]
https://github.com/NicoHood/HID             [Arduino HID project "HID-Project.h", (RawHID object)]

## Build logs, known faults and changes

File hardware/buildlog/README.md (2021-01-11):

# Build Log
This is a basic build log, it's not a blog yet but feel free to ask if you want additional
documentation or something more than just few steps and some photos. I've never published
a video for it so if you prefer to have something better just ask.  

Here are just basic steps and keyboard making in a long journey, I've worked on it in my spare time
and when cheap (or free) materials were available. This is just a basic photo doc.  

---

### It all started with a scrap piece of metal
With a cheap 2mm stainless steel sheet and my jig saw I've cut keyboard base plate, basic keyboard
shape has been created with classic http://www.keyboard-layout-editor.com/. All link and resources
are readily reported in this project as well
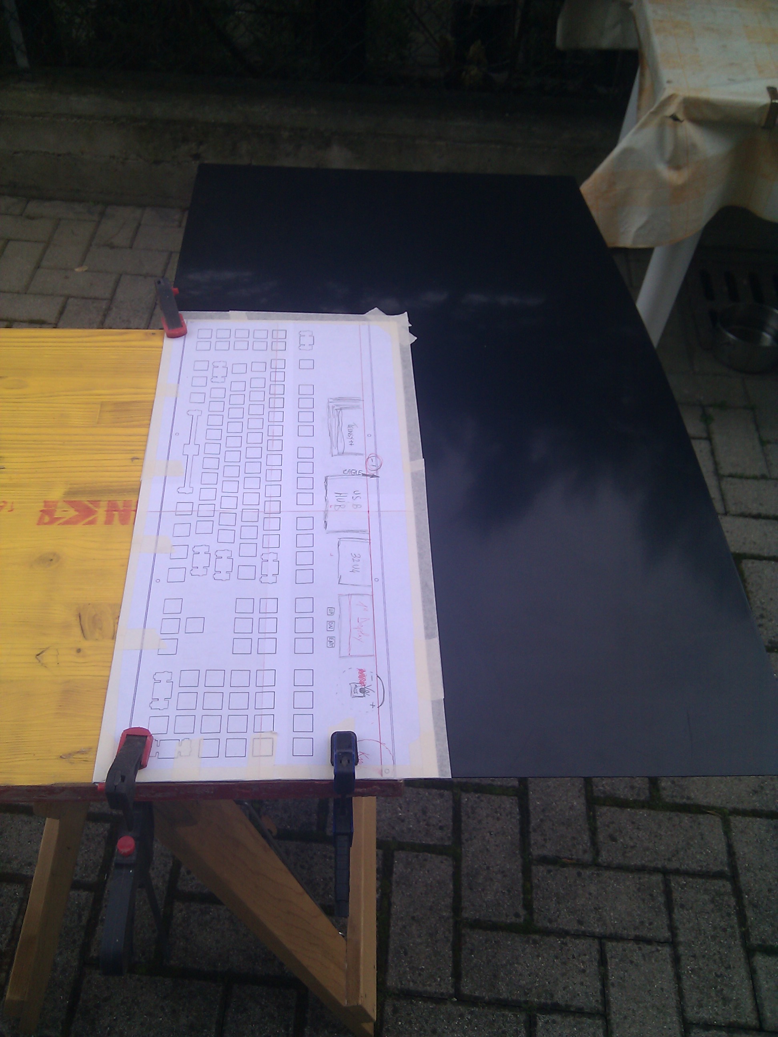
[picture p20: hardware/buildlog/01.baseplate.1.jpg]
metal foil


A basic cut and some sanding on the edges. With a drill I've placed holes where necessary and with a
cutter and my files I've shaped proper key housings. This is not a difficult operation, just a little
bit boring but it's still easy.
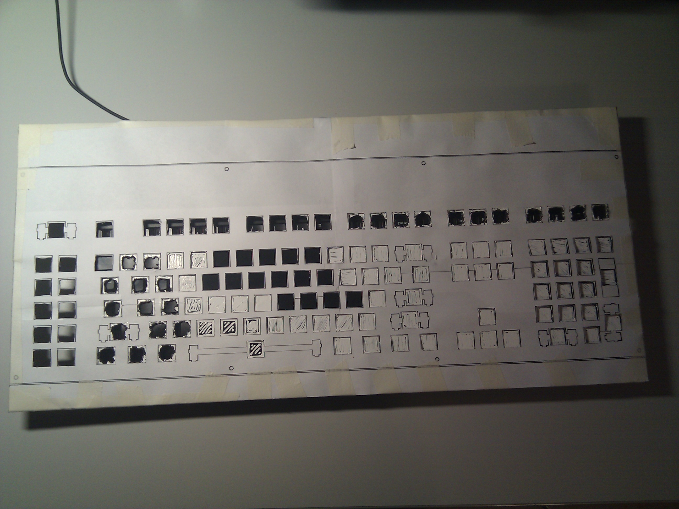
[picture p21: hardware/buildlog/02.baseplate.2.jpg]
drill,drill,drill


With a marker I've painted key housings, on the left there're few completed squares, in the
middle few of them are drilled, on the right a lot of work has to be done.
Still boring but quite easy too.
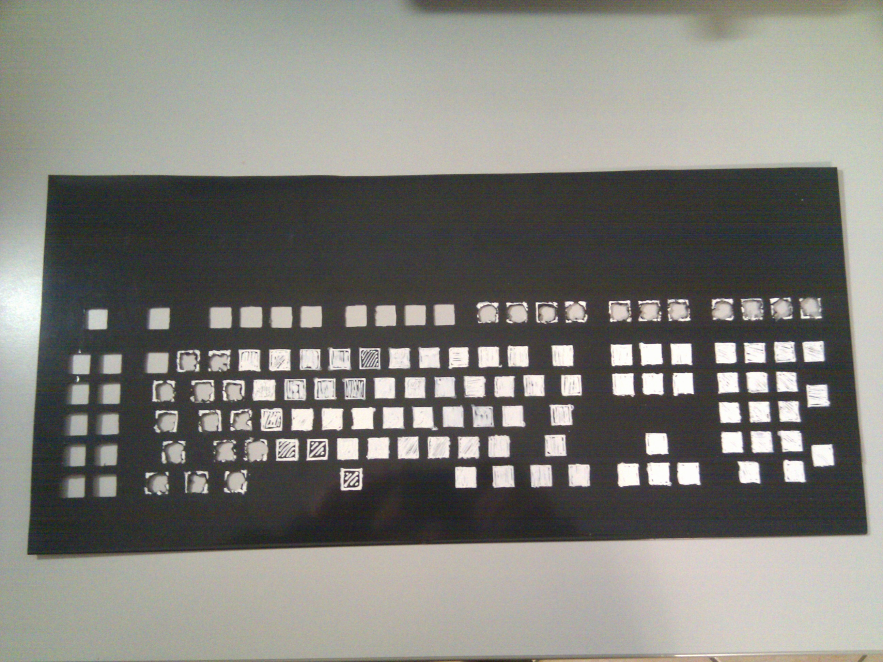
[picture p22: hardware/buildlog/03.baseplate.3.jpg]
still a lot of drilling


After a long while and a lot of repetitive job with small files I finally have some nice metal
artifact. If you're on the cheap and you don't want to waste money on CNC machining this is what you
can do, if you've some money and you can afford a professional work is up to you to get something
better. DXF, EPS and full specs are available
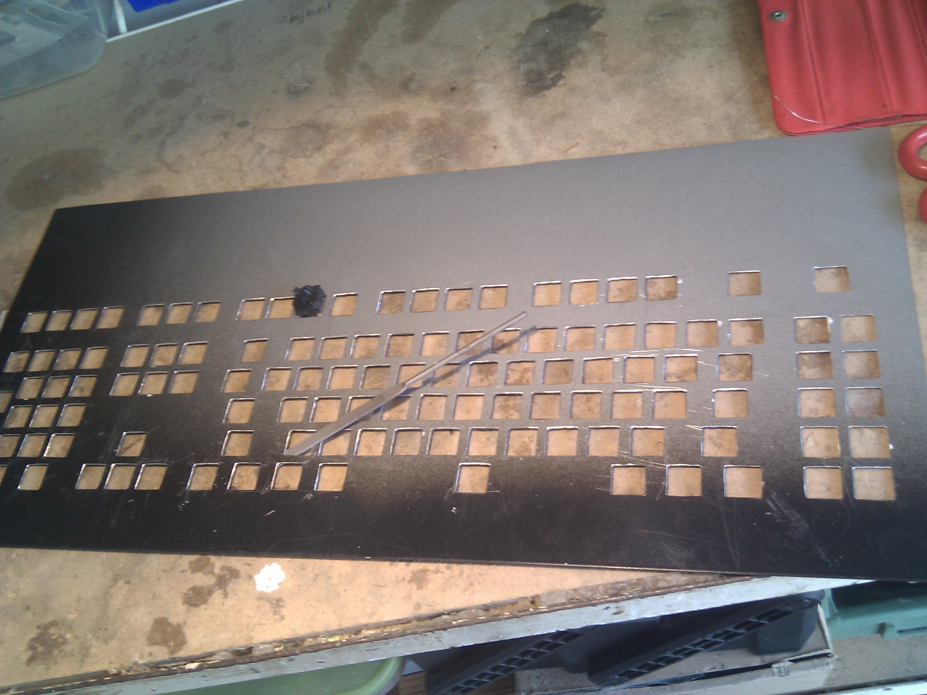
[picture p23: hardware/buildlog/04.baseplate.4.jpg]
nice metal sheet


After a lot of refining work with my files I've bended it with a squared steel bar. I've started
from the bottom in order to keep clean folds, I've avoided to use an hammer because I don't have
professional squaring tools. Take your time (and your patience), you cannot do a fold twice.
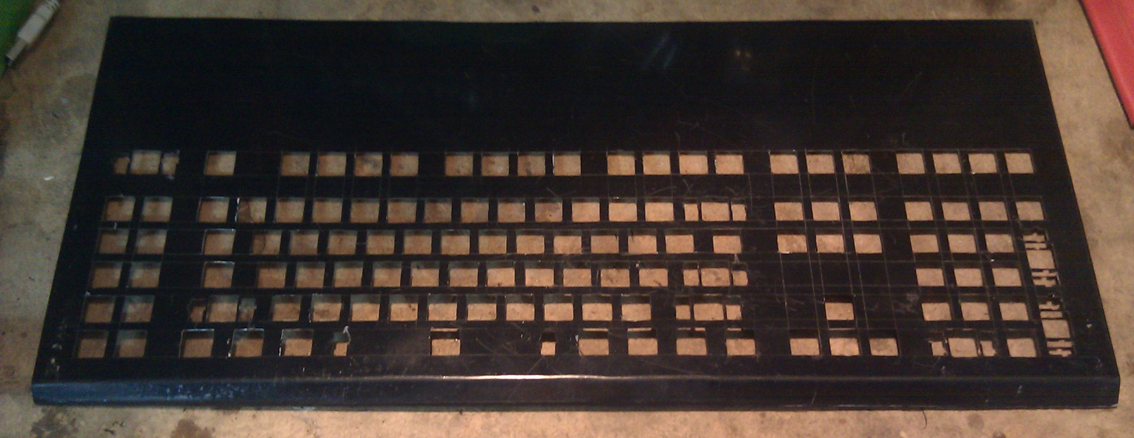
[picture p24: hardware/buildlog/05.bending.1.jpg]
bending metal


On the back there's an experiment I've done with threaded rods and metal putty in order to 
strengthen the chassis but:
- there's no need to strengthen a steel frame, it's still sturdy and solid even without them
- my metal putty and stainless steel don't match at all, even after several days these two materials
weren't perfectly linked. Result was really poor so I've removed them after a while
- it really sucks, honestly, don't do that. Lesson learned

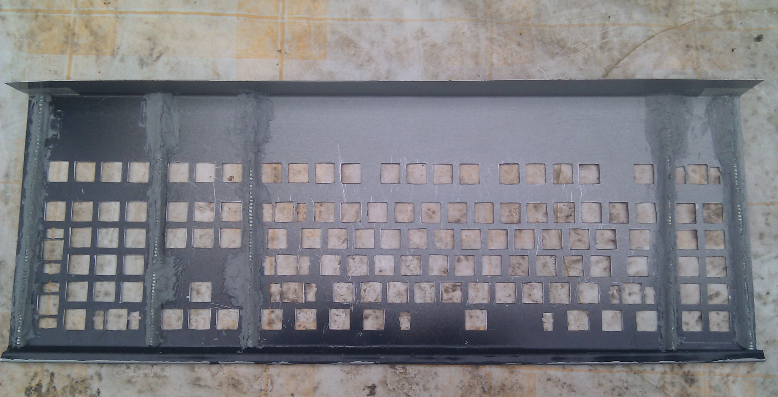
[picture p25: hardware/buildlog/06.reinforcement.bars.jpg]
steel rods


After removing the rods I've finally gently bended the upper plate a little bit more (with a towel)
in order to have a clean and nice curve (like Type5). There's no rule of thumb, it's just my flavor.
I've finished when I was happy for it.  
After that I've removed original black painting and I've sanded a lot (40,100,150 grit), stainless
steel might be hard to paint when it's not properly sanded
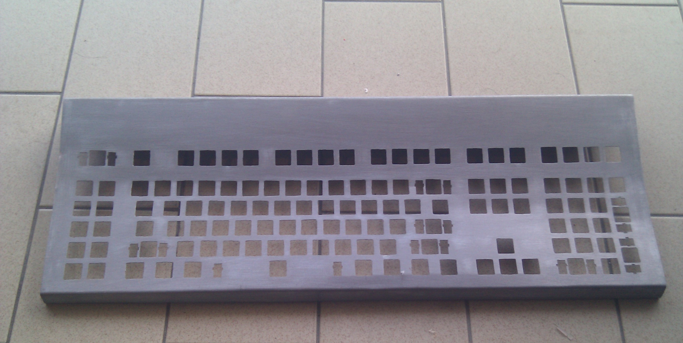
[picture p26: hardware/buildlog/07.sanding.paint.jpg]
a lot of sanding


It's not too smooth in order to avoid problems with paint or primer but it's clean enough to correct
previous defects and remove previous color.
In this photo you can clearly see the U-shaped fold on the front and light bending at the base plate
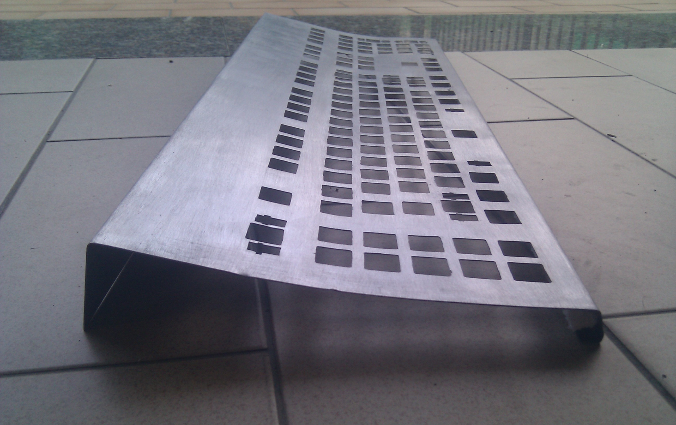
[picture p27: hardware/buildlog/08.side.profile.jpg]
sanding, side profile


After sanding I've applied some
[Oogoo](https://www.instructables.com/How-To-Make-Your-Own-Sugru-Substitute/)
on the inside to fill the gap for future enclosure. My version also has a small part of neoprene
glue for extra hardness and better cohesion with metal. It's still quite soft but it's like some
kind of hard rubber. This part is the key for keeping the back plate in place.
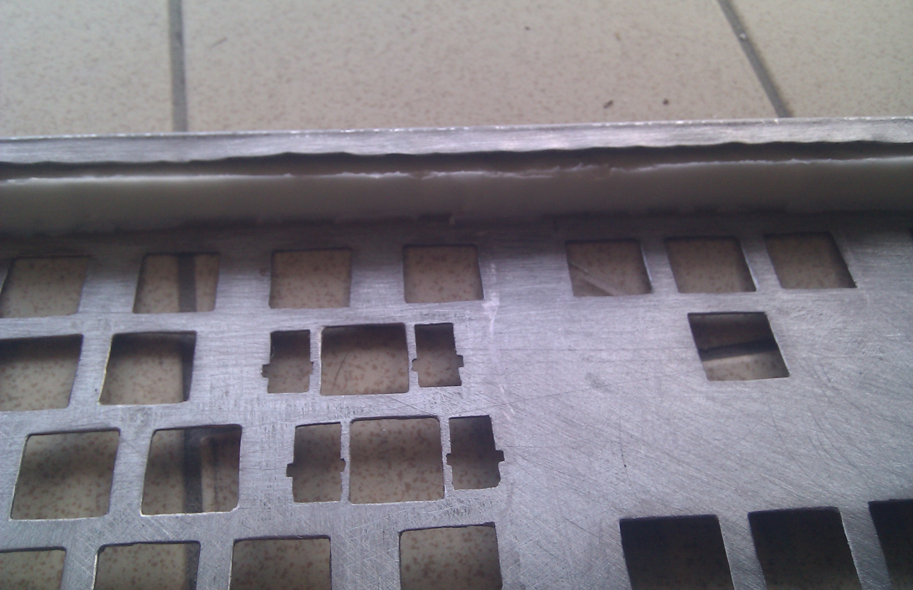
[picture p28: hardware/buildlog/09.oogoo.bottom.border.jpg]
oogoo as filler


Due to its adaptability I've applied some oogoo for shaping sides as well, it's like doing some
mold but due to its strangthness it's a perfect material for filling gaps. This time I've also
added some black toner to the mix in order to have a black shape. With a small piece of steel
I've simulated the back plate so the side is perfectly shaped. Neoprene glue accelerates the
oogoo chemical reaction and it dries quickly, you've to be fast to apply the mixture.  
When it's dry you can remove excess parts with an utility knife. You don't have to be too precise 
on the inside. On the outside I've used a Dremel to perfectly sand it before painting.
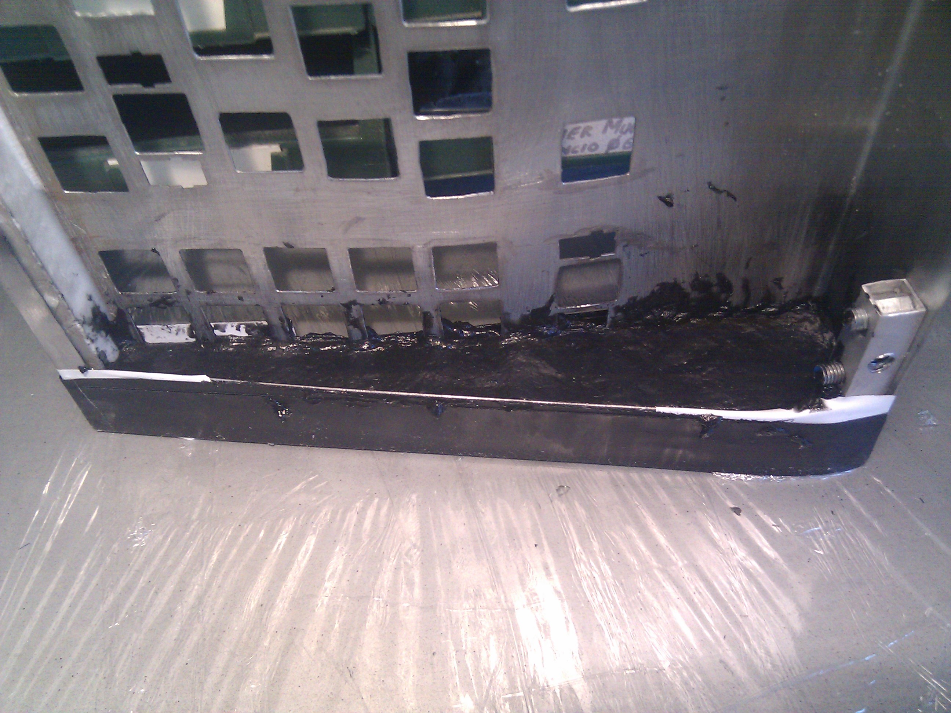
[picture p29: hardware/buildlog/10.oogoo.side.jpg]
oogoo on both sides


This oogoo is really solid even if i've added some epoxy glue on borders to keep it in place.  
The dremel is the perfect tool to shape this material even if after some sanding the color tends
to be light grey, fortunately it keeps spray paint really well.  
I've also attached squared bars with nuts inside it and fixed with bolts, this would keep the back
plate in place.
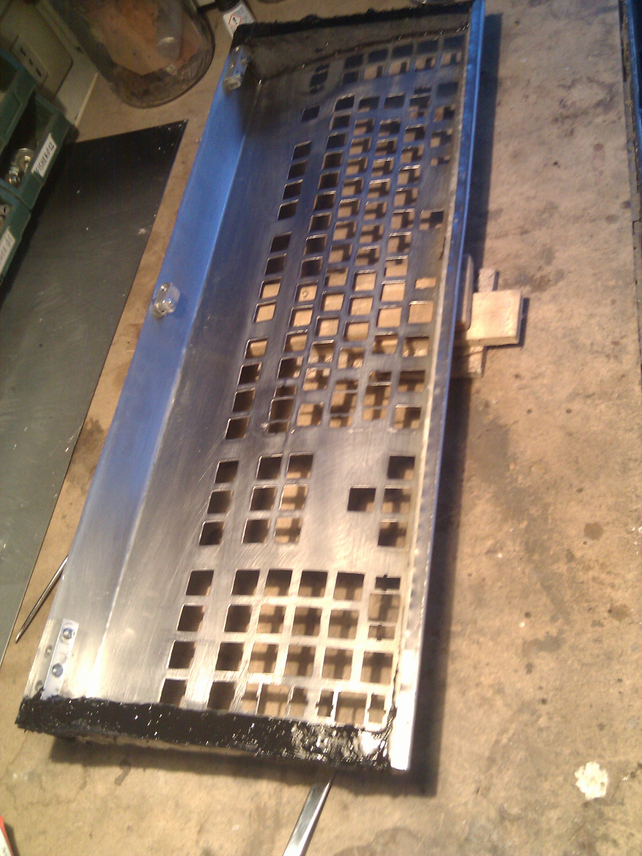
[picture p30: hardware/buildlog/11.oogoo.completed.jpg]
oogoo completed


Stainless steel is hard to paint when it's not clean or not sanded enough. To avoid troubles I've
also applied a coat of primer. It's a zinc-coated primer I've previously used as base for a
cast iron stove painting. It's a raw color and it's a little bit thick but that's ok. I'll use this
primer as plaster to cover steel imperfections.  
From this photo you can see holes on both sides, this is where rotary encoders will be placed.
There's a big square hole on top where the LCD display will go.
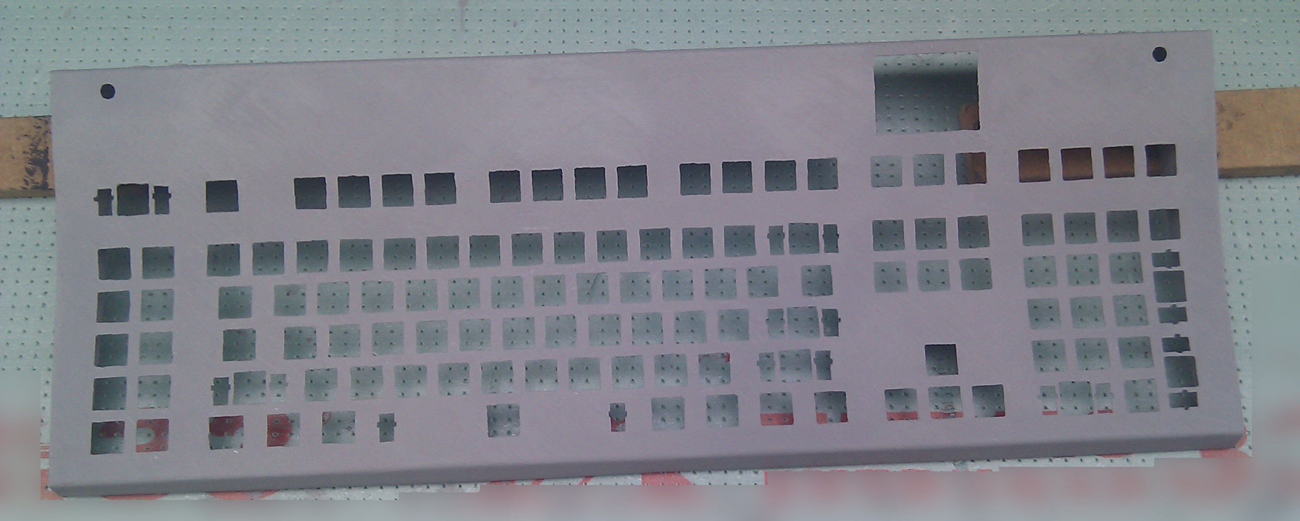
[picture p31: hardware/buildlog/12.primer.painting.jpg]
Primer on steel


More sanding over the primer. I've sanded with 180 and 220 grit over the primer to have a uniform
coverage, even if some primer has gone it's not a problem at all. I'll add another coat of paint
to protect the steel.
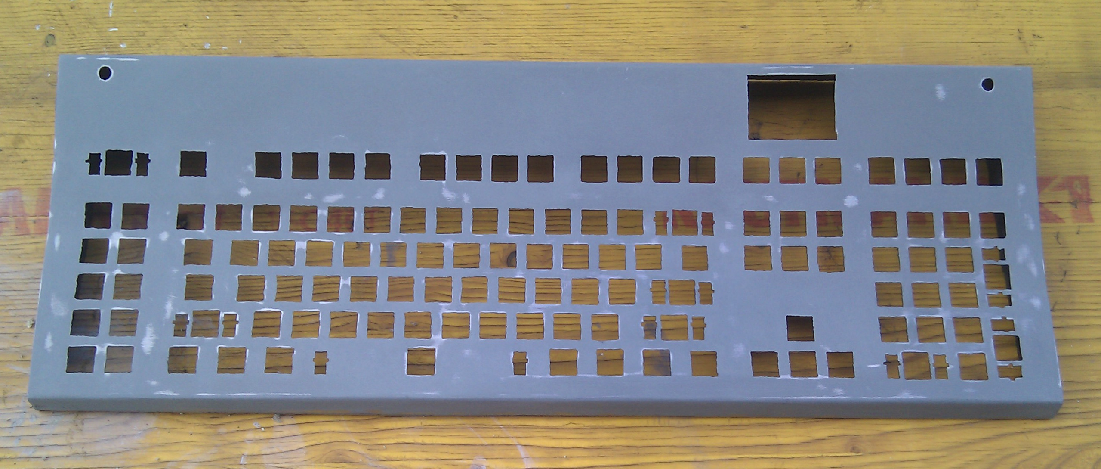
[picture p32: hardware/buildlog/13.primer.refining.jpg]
now sanding


I see a keyboard and I want to paint it black...  
Now with a spray can I've covered it with first coat of black paint, result seems to be good even if
it's a cheap spray can and I'm not a coachbuilder nor an experienced pro with colors.
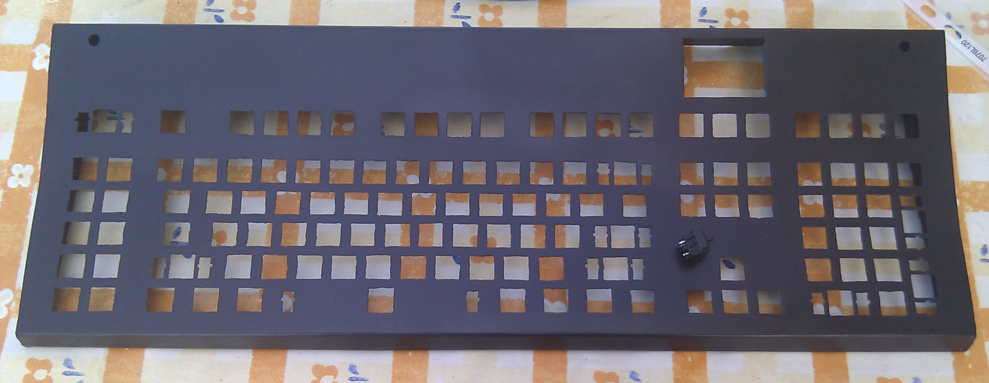
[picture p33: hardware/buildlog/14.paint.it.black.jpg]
paint it black


In this photo there are two different things.  
In order to avoid short circuits I've recycled plastic films from cellophane bags, I'll cut them
later on with a surgeon's knife.  
The orange part is polycarbonate, this will keep plastic films in place and the keyboard circuits
insulated from the steel. I have also created some space for the USB hub and the power jack in the
middle of the board
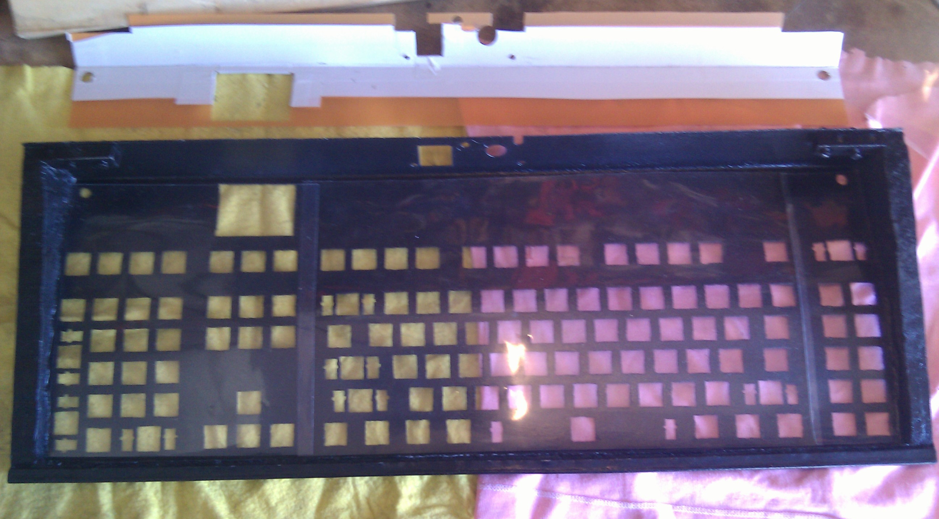
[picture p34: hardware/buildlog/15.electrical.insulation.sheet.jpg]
electrical insulation


Now with a spare piece of metal (was a hard disk bracket) I'll keep the polycarbonate in place and
I'll also add some sturdiness around external usb ports and power supply jack. Handsaw a drill and
some files, as usual...
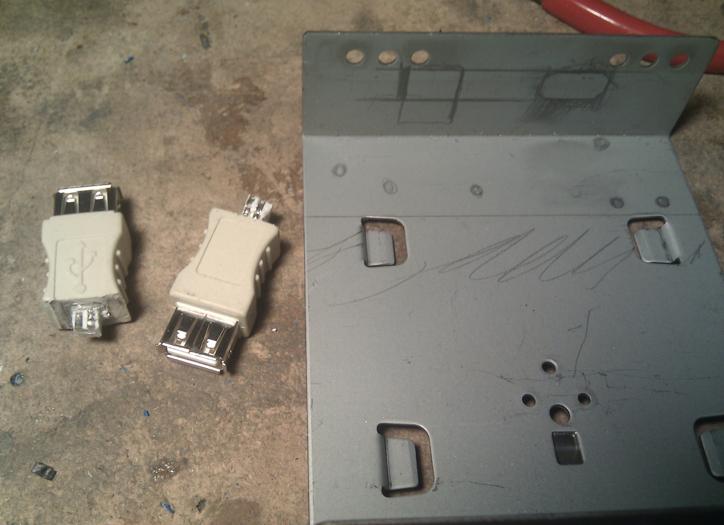
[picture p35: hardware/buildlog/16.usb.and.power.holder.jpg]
USB and power holder


Now it's time to work on the display. These cheap arduino LCDs also have SD card storage.
I've had planned to use I2C ROMs and connect them to the Teensy but this SD slot seems to be a
really good opportunity. You can see full specs on the circuit in the dedicated section.
The only problem I've it's the size of the SD card.
SD Card inserted in the slot collides with the cherry keys so I've cut the card to save space,
this is an old trick I've learned from Raspberry Pi forums and it's still valid.  
**2Gb SD card** is a lot of space for saving keyboard macros and since it will be mainly used for
reading (storing new macros is still possible but not that common), I think it's a good solution.
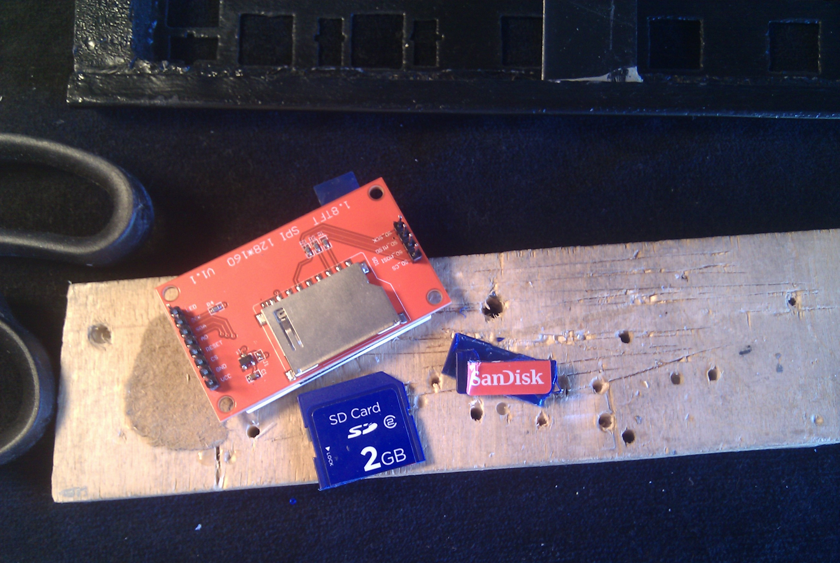
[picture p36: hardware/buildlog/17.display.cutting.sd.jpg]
Cutting SD


Circuit has been built on a protoboard, through-hole components commonly available, no smd parts.
Something you can easily obtain locally or you've already in your bench. As usual see the circuit
specs of the project for further details.  
From the picture two rotary encoders are connected to the Teensy. Knobs are temporary for testing
purposes
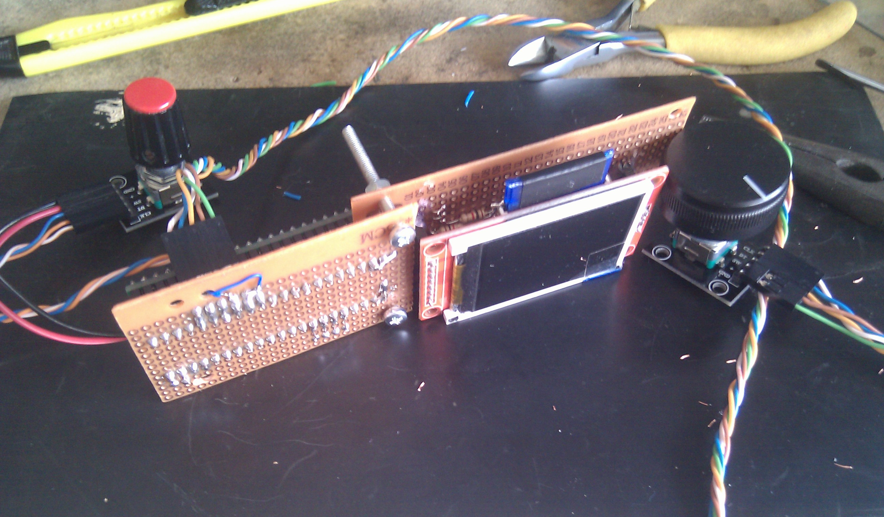
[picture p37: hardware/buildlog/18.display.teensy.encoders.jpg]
Assembling circuit


More painting (three coats of black paint totally) to obtain a matte effect, I
personally don't like a shiny effect, also because it gets scratched quickly. A quick coat with a
transparent varnish and I finally have something to work on.  
The whole world use PCB mounted stabilizers, I cannot use them so surface mounted stabs are
my only option. Costar are noisy but easier to mount on, Cherry stabs are a real pain to mount.
With a caliper I also have measured plate thickness and it's now 3mm width so slightly thicker than before.
These stabs are fine on 2mm _aluminium_ plates, 3mm steel is a madness. Take your time and act wisely
in order to avoid scratches or damage the plate.
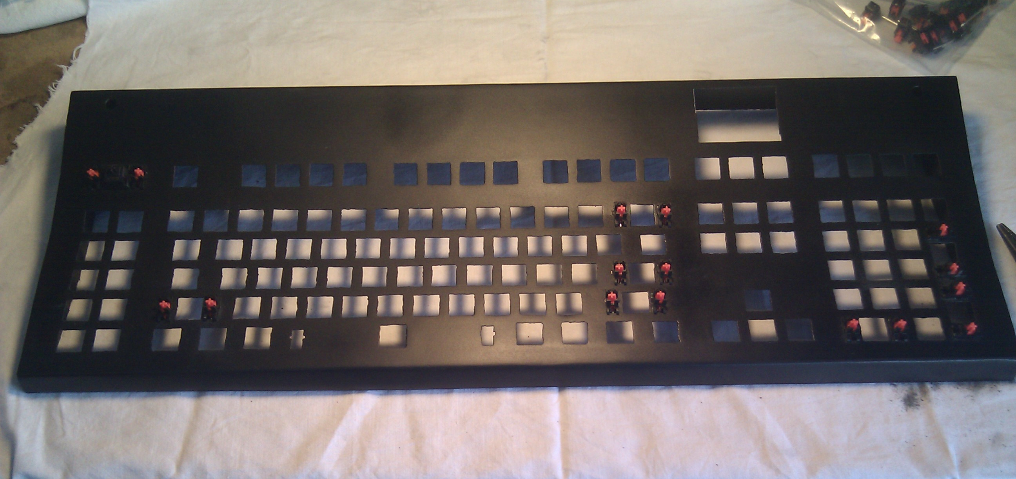
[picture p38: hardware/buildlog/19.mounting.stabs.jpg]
Mounting stabilizers


Zooming on stabs and holes is interesting because square holes are not so perfect anymore and stabs
are not properly aligned.    
Stabilizers positioning is easy because you can fix them with a file and even if they're moving
a little it's not a problem because when keycap is applied they won't stuck, they just need to be
lubed to avoid rattling.  
Square holes are rough due to painting deposits and this is absolutely a boon, Cherry keys will
stick on that like a gasket. Remove excessive tailing (if any) with a file, not my case here.
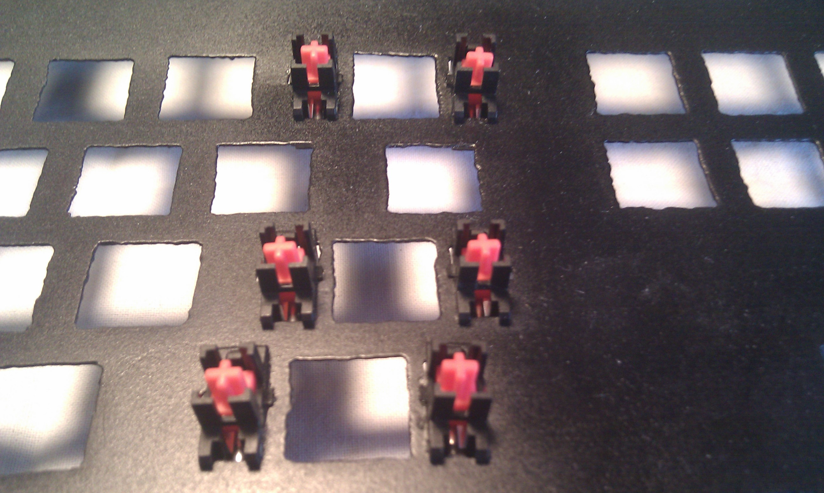
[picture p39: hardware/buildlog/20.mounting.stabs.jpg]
Zooming on stabs


Placing keys on the plate is the only fun part of this process, this is what I see often when
I look at other tutorials where someone bought a kit with everything and they just need to
assemble ready made parts... well, it's not my case.  
I'm using Cherry Black keys as reported in the BOM. These keys are part of two acient AT/XT
keyboards I've had around for a long time. Manufacturing date reported on those keebs was _1988_
so I guess these keys are probably from the 1984/1988 period. There's a lot of discussions related to
original and newer cherry keys, I couldn't be happier for them. Black series are fully linear,
ultra silent, without udible click and mostly recommended for gaming, I love them
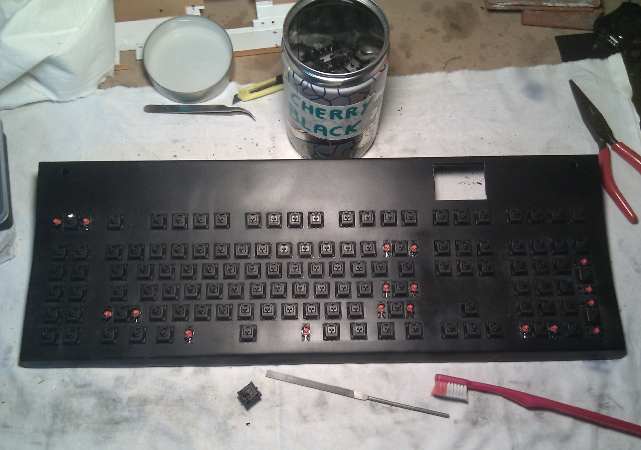
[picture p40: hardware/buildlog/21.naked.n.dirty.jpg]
mmm Naked board...


Now it's time to use the surgeon's knife to adapt the thin plastic foil with square holes for the
keys, it takes a lot of time but not a problem at all. Small dots of mastic will keep the plastic
glued to steel, it doesn't has to be nice, it just works
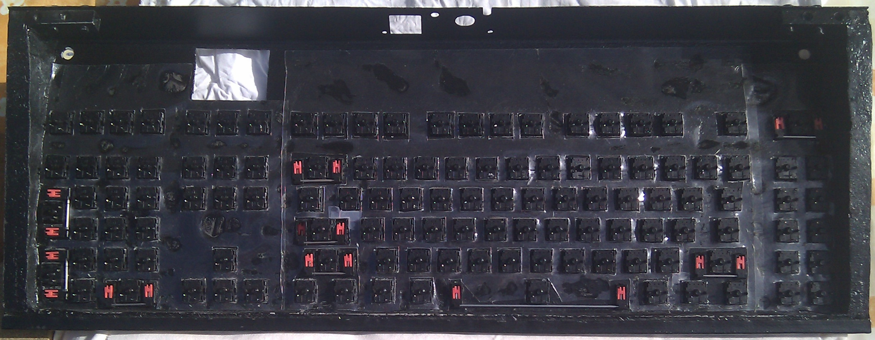
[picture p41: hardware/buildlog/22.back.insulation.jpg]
Insulation ? Yes please


Now the real mess: manually handwiring everything, 20 cols x 6 rows (119 keys). It takes a lot of
wirewrapping wire (no, I don't have different colors for it) and a lot of patience. With a plan
(you can see the print there) it's just a matter of days.... I envy 40/60/75% builders in this
case this one is really huuuuge
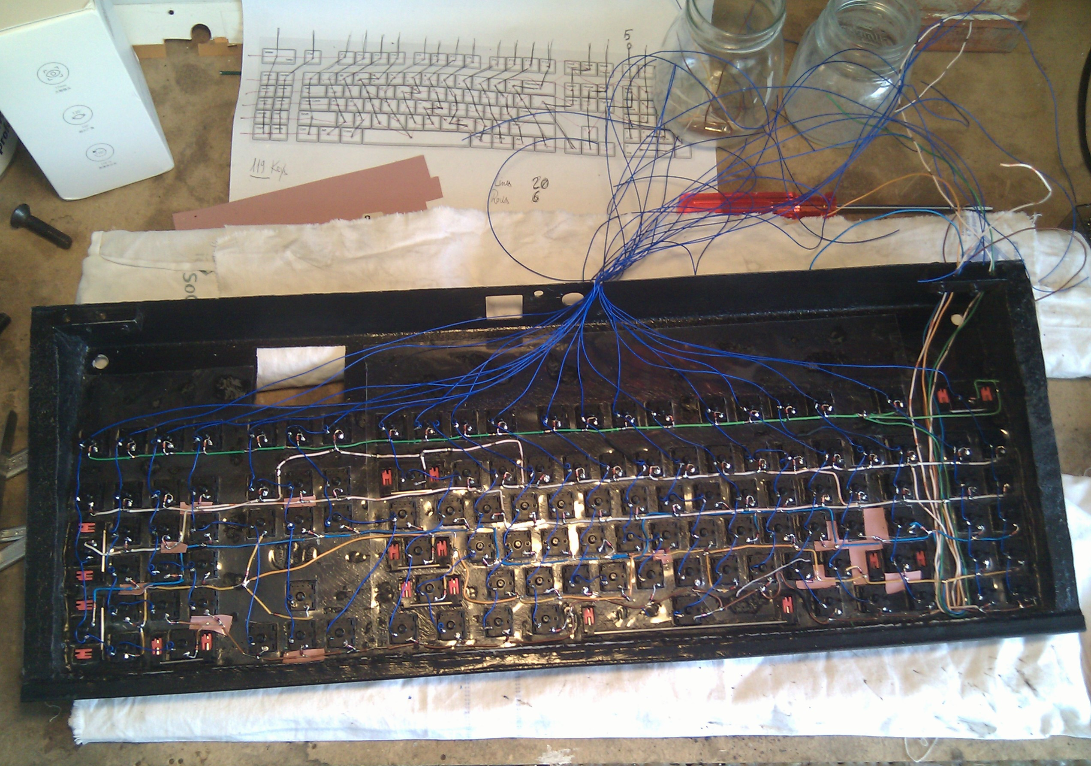
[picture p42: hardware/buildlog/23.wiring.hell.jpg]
Handwiring fans unite !


Now it's time to place the polycarbonate sheet and block it in place. It will keep its position
thanks to two rotary encoders (on both sides) and with the metallic bracket where PSU jack and 
USB Hub are placed. Hub has 4 ports, two are used on the inside with two Teensys, two are
accessible from the outside for your favorite peripherals (cellphone, tablet, headset, ...).  
USB Hub has been slightly modified by cutting the power pin coming from Host. Host and this hub
have common ground and data pins but power supply has been taken externally from a dedicated
PSU jack (5V). From the same connector power supply will be granted for the entire board
(Teensy, led backlit, LCD, external USB peripherals). Use whatever 5V external PSU you have, in my
case I've used a 5V 2A unit.
See picture above for further details
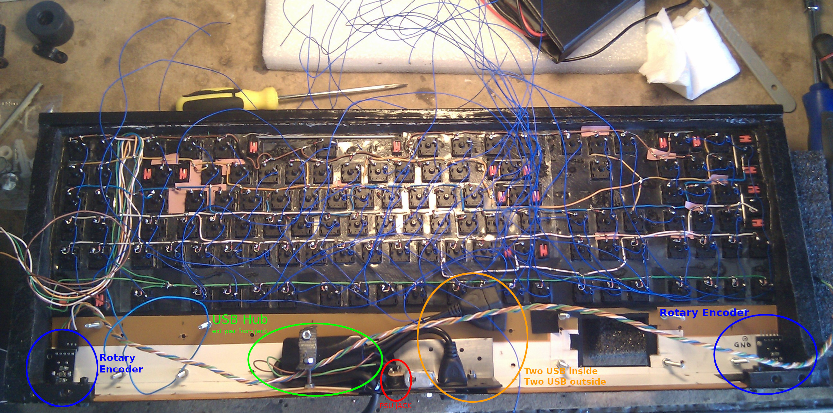
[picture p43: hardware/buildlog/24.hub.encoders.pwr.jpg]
assembling electronics


Time to cut some cables, adapt wirings and place Teensy boards.  
Here's some clean wiring with Rows and Cols connected to one of the two Teensy controllers
(on the left), this has the QMK firmware loaded and direcly controls the keyboard matrix
(20x6, no ghost keys).  
On the right side another Teensy board controls: rotary encoders, LCD display, SD Card, led backlight
and has access to the same USB hub, so it's like having two keyboards in one shell.  
These two Teensy are connected together with TTL serial port (Arduino __Serial1__) and exchange data,
configurations, display information and so on. I'd like to protect SD card data so I've thought about
a potential login process at startup or a way to input user data after boot
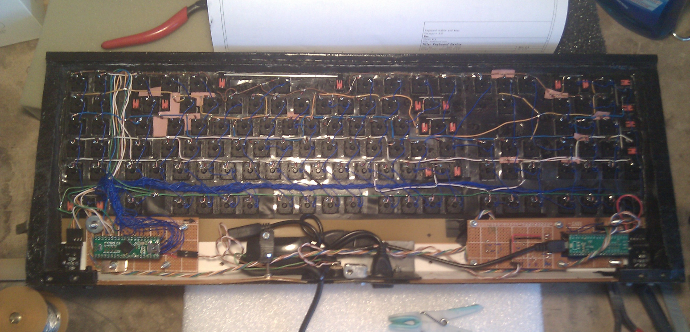
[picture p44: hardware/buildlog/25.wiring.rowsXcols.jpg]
Placing MCUs


To control led backlight I'm using a Darlington Transistor (see BOM) in order to avoid direct driving
from the MCU. TIP112 is more than enough for my LEDs because I won't use them at maximum light, for
the same reason the heatsink is not necesary but it's better be safe than sorry, as usual.  
Connectors don't save space and manual wiring is always better but with this method I can
disassemble or enhance the project without troubles
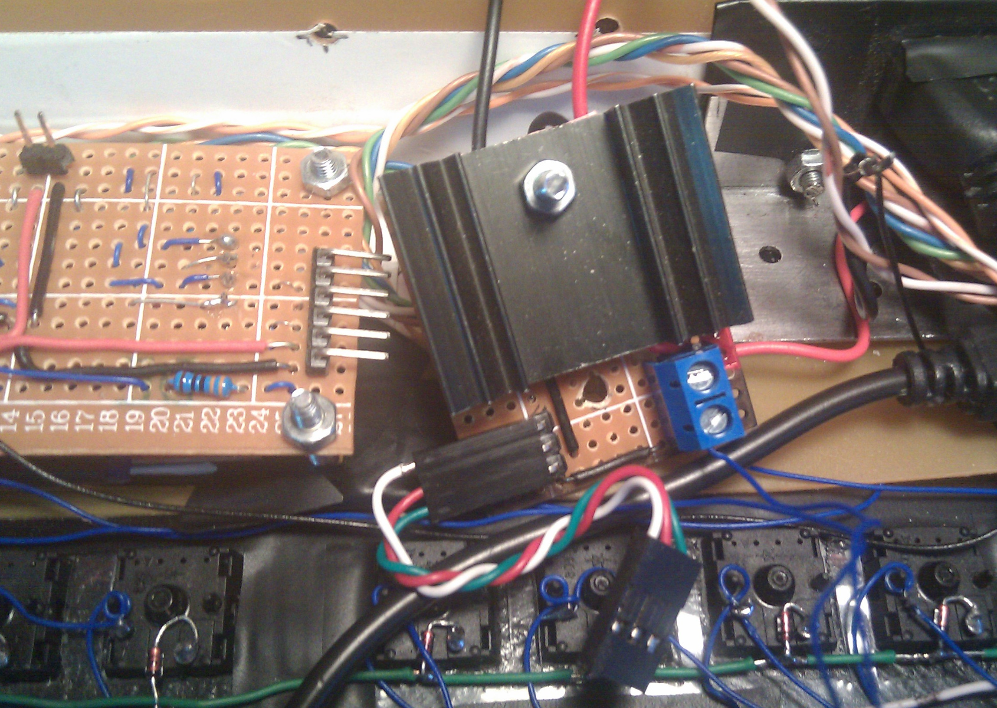
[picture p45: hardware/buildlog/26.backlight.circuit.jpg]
driving backlight circuit


So you think I'm set with manual wiring because the keyboard is now working ??? **Wrong**.  
Now it's time to start some real pain with led backlight wiring. There's no polling nor multiplexing,
each single led will be driven by the Darlington Transistor.  
Only two leds are driven directly from the Teensy: _Num Lock_, _Caps Lock_. Under the teensy board
(upper left) there's a piece of heat shrink tubing with two resistors, these are connected to the
two leds and the MCU.  
Every other key on the board has a led, a resistor in series with it and a connection to the
Darlington. Now you'll start seeing a lot of wiring mess, resistors and heat shrink everywhere
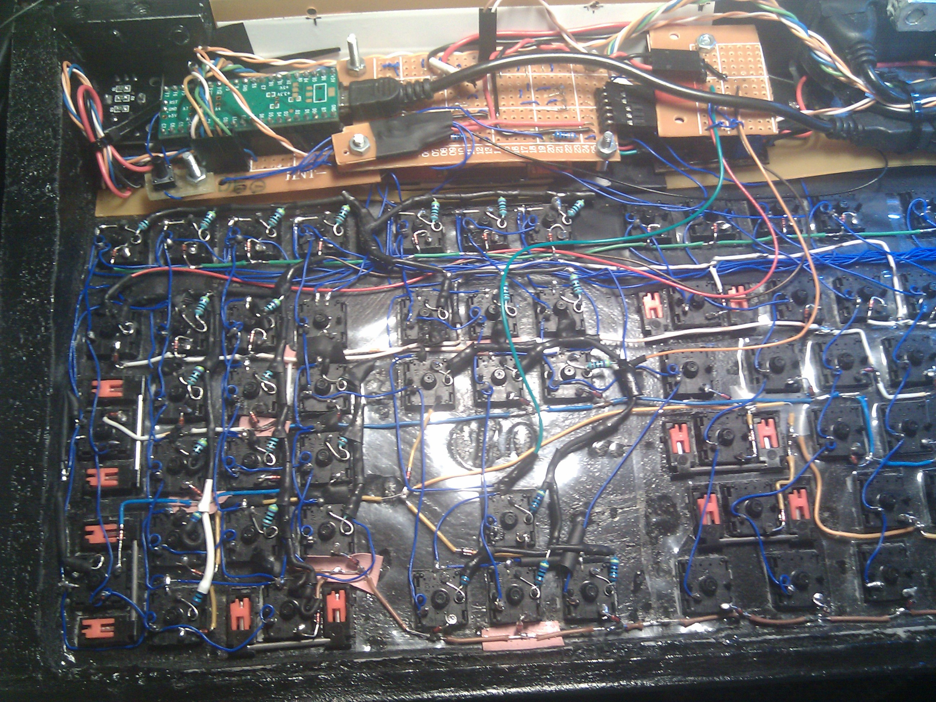
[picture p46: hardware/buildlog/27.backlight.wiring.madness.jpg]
Here comes the pain


There's a lot of wiring, patience, madness, resistors and heat shrink tubing. Take a look at the
next photo with wiring without backlight (left side) and with backlight (right side)
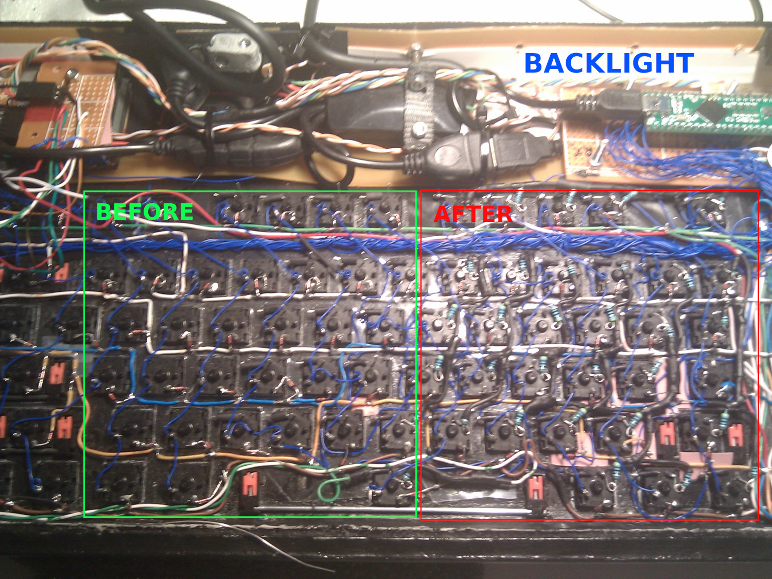
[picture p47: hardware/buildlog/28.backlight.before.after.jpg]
wiring backlight, before and after


Now it time to test all this stuff, after carefully assembling everything and a quick test I finally
ended this crazy thing. There are tens of meters of cables in there. You better have a lens for
this kind of work
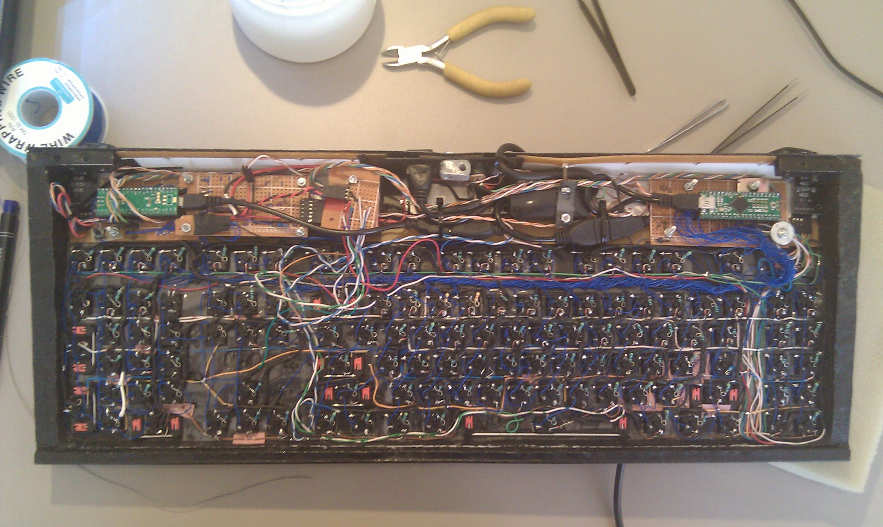
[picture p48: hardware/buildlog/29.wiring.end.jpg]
Wiring ENDED :)


Now the fun part with keycaps. Pay particular attention to large keys with stabs, place them 
before everything else, it won't be easy to put them later if you make mistakes or if you've
problems with stabilizers placing.
When you're confident with these large keycaps and stabs are not rattling you can place other 
keys too.  
If you're building an average keyboard like me you already know you've to lube keys and stabs. I've used some lube for stabs (let the flamewar begin) and Oil from sewing machines for each single key.
If you're building a top class keyboard you're already familiar with chemicals and probably you've
already spent 10/20 bucks for top class lubricant.  
Now a small note on knobs: these are not real knobs. I'd like to have a 40/50mm knob and 30/35 are
too thin for me. I don't have access to a 3D printer and that's why I've used jar caps. These
caps were black painted and filled with oogoo (on the inside) to have some weight and keep the
rotary encoder screw firmly placed in the middle
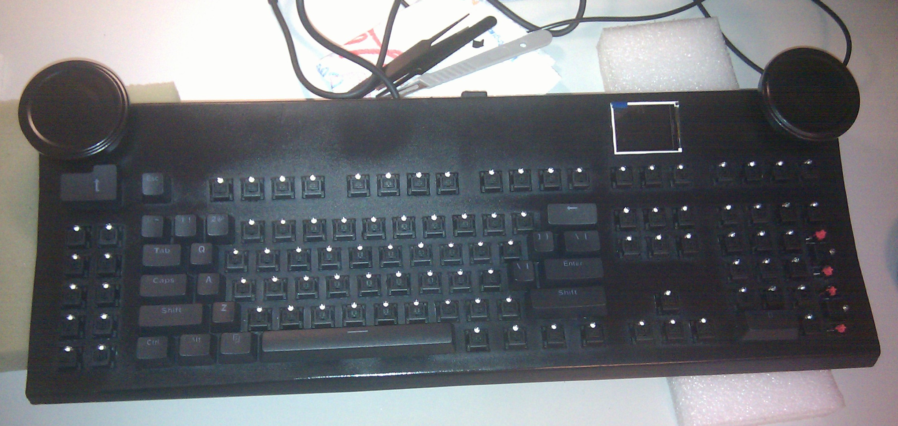
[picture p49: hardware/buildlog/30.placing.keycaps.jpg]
Finally placing keycaps


Before placing the backplate in place I've added some adhesive paper to avoid short circuits.
Zoom the photo and take a look at the borders for further details. A steel frame is awesome but
it requires extra precautions
Insulating backplate

### Finally, something usable
Yes I finally did it, real photo from a cellphone, not photoshopped (gimp: "crop to selection" only)
to center the subject but nothing more. Now it works I'll surely improve the software but the hardware
side is almost complete. **Is it finished ??  No, it's not**  
Basic keycaps are fine but my keyboard requires extra keys and I want to keep the same style.
I've placed F1...F4 keys below the right encoder just to fill the blank. Hopefully I'll replace them
real soon. On the 10keys island on the left side I've placed 10 R4 keys because I'm still waiting for
R1,R2,R3 keys from AliExpress.  
I'm buying transparent keycaps because I want to paint them black from the inside and then carve
letters or symbols (from the inside too), painting on the outside with nitro or acrylic is not
preferable because your fingers will have a different feeling with them. Even more, after a short
while painting goes by.  
**Windows key is pure evil.** I need to buy something different for the right "super" (or meta) key
It's here :)

Rotary encoder knob is really cool even if it's just a jar cap. Filling it with Oogoo sounds nice
because when you use it it feels quite heavy and it doesn't swing at all.  
**UPDATE:** replaced them with big fat self made wooden knobs, see 
[try, build, fail, repeat...] section below  
Browser button (big fat enter placed horizontally) was just a filler because I didn't have a 2U
keycap but I really like it, I won't replace this key.  
R4 transparent keycaps are nice in the first two rows but inappropriate on the remaining lines,
as described above I'd like to have a full line: R1, R2, R3, R4 keys, black painted and properly 
carved so still a work in progress
Final view on the left

Display is fine, I've black painted the borders but I still need to place a small filler mask to
to avoid minor external light effect, not that bad anyway
Final, LCD Display

Right side view. Black painted Oogoo is nice. At the base level you can see small felt pads raising
the keyboard by few millimeters, without them the keyboard could scratch the desk
Right side view

Another overview of the board. On the top you can see the USB cable, the power supply cable and
two usb ports. No visible screws or other joints on it
overview

Keyboard firmware is basic but fully working, not good looking but fonts are crisp and clear, 
things are visible and hopefully I'll dedicate some time on it
- "main" screen: numlock, capslock, OS type, current keyboard layout
- "main menu": overall configuration of Host Audio, Backlight, Kbd/mouse settings, Games
- "led backlight": you can make it bright or totally off, PWM controlled from MCU
- "macro mode": with the right knob you can enter repetitive key sequences (macros menu selectable)
- "audio volume": to control host audio with a knob
- "PONG": Two rotary encoders ? Pong obviously. There's more on the way (Arkanoid, Pacman)
- "setup": Scroll size, inactivity time, firwmare upgrade and so on  

Encoders are big and used to control the display but also usable for host interaction (mouse wheel,
X/Y axis, volume control, ...)
screenshots

**try, build, fail, repeat...**  
I really like these big knobs and recycling two jar caps seems to be easy and quite good, overall profile is smooth
and they nicely do the job but I'm not completely satisfied yet. I've decided to create something heavier and tall,
something like those giant knobs I usually see on professional video editing consoles.  
From scrap wood (as usual...) I've created a big knob with just a drill and a file (unfortunately I don't have a lathe),
it's rather big (70x25mm !) and I really like it, I've applied the same black spray color after two layers of primer.  
It doesn't even seems to be wood after the black paint, see for yourself
big ass knob

### Transportation
To transport this keyboard I've taken some spare (recycled) cardboard and I've created a box, for free.
I've designed the shape and cut the cardboard with an utility knife, project in previous directory,
here is the result:
keyboard box

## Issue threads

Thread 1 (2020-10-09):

Clone and ship me one ?

omarali-me, 2020-10-09:
Hey dude, beautiful work.

And I would love nothing more than exactly the same.
Would you be willing to make a replica ?

andreabenini, 2020-10-19:
Thanks Omar.
I froze my reply for a while to understand whatever it takes to create a new one. I've documented each single step of the production process, it was created to be a cheap project with scavenged parts and I was able to achieve it mostly because big savings were related to switches, pcb and keyboard frame. Brand new hardware parts for the project costed me ~30/40$ so I'm quite happy about that.
I had at my disposal two broken AT/XT keyboards so I collected switches from there (~50/60$ switches value), some 2mm stainless steel and plenty of time. Manual work is what made the real difference, from drilling steel to handwiring everything (two times: keyboard matrix and backlight), lockdown helped in this case...
Firmware programming is almost complete and electronics part is simple.

I've had requests (like yours) after the HackADay article effect so I'm considering it, I'm now evaluating a small batch but CNC steel machining price is insane and spending 2/3 months to manually work on each single piece is not a viable option.
I'll try to experiment few things like CNC & PCB milling to see if I can work on a small batch (collaborations are warmly encouraged) and I'll surely publish info here where available.

Comments Welcomed :)

Closed 2023-10-25.

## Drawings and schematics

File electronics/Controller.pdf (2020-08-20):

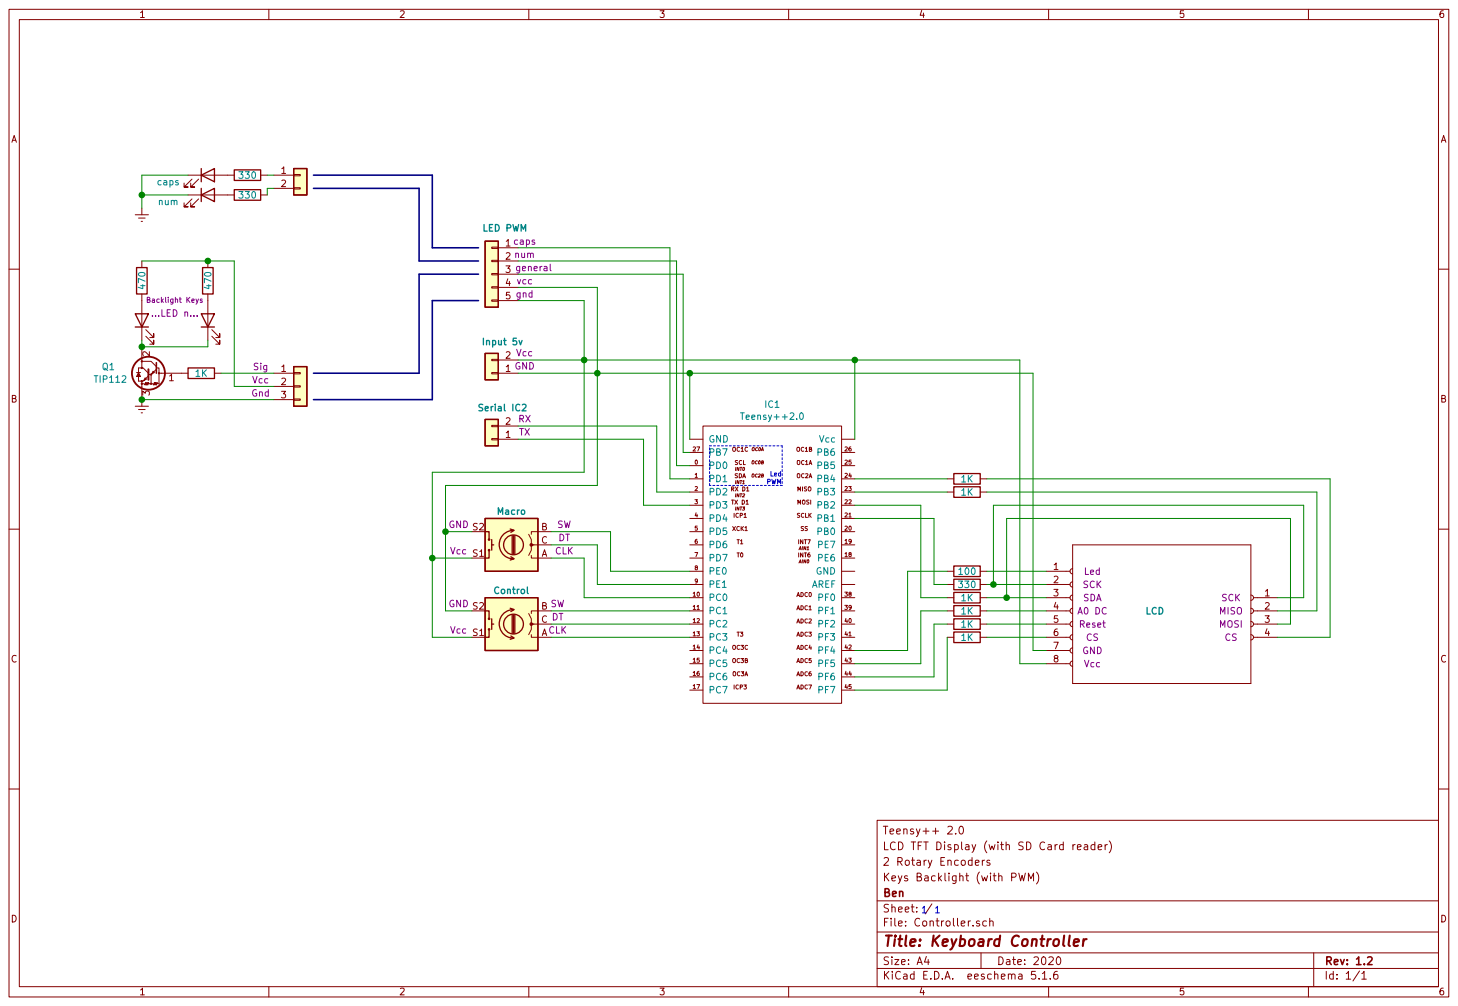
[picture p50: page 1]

IC1 Teensy++2.0 12 Serial IC2TXRX 12345 LED PWM
caps
general num

LCD TFT Display (with SD Card reader)
2 Rotary Encoders
Id: 1/1 Title: Keyboard Controller File: Controller.sch Sheet: / Ben Keys Backlight (with PWM)

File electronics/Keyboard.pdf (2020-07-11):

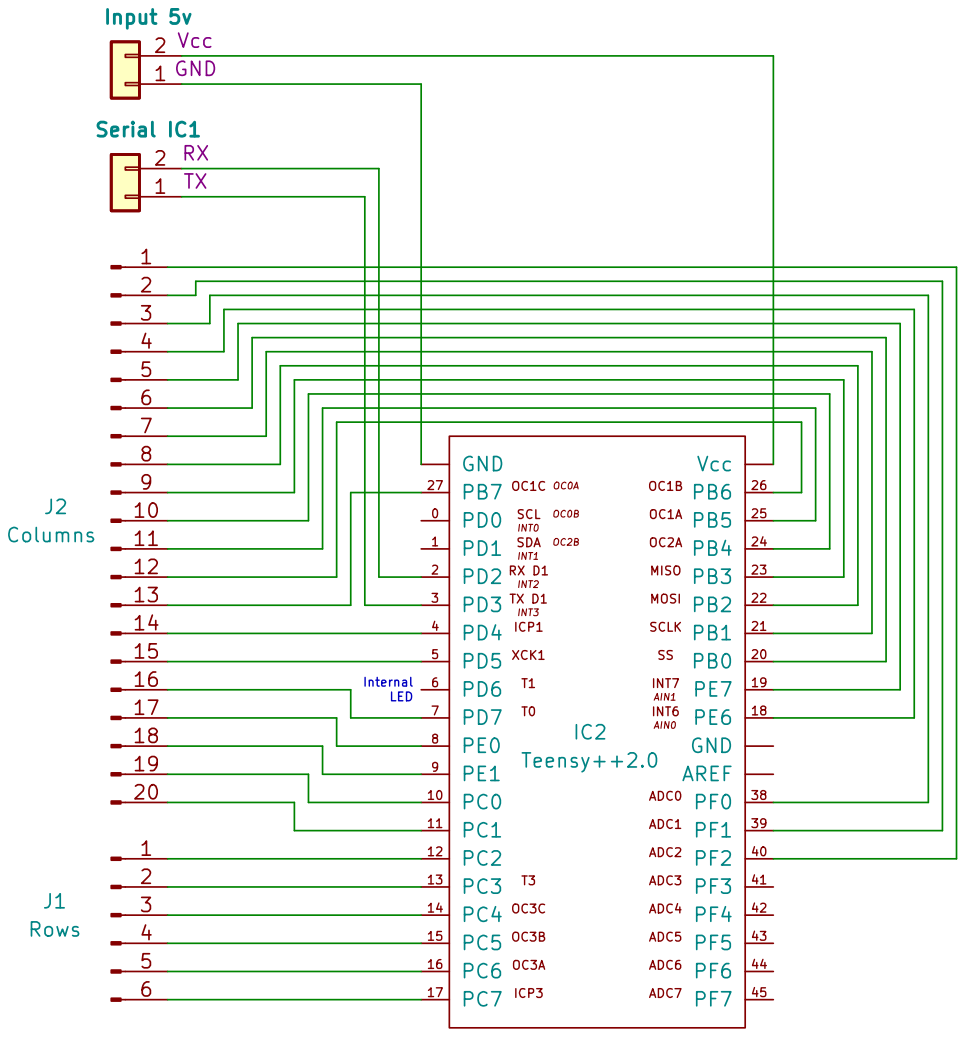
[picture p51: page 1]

Input 5vGND
Vcc 123456
Keyboard matrix and keys 12

Teensy++ 2.0
File: Keyboard.sch Sheet: / Ben

Id: 1/1 Title: Keyboard Device

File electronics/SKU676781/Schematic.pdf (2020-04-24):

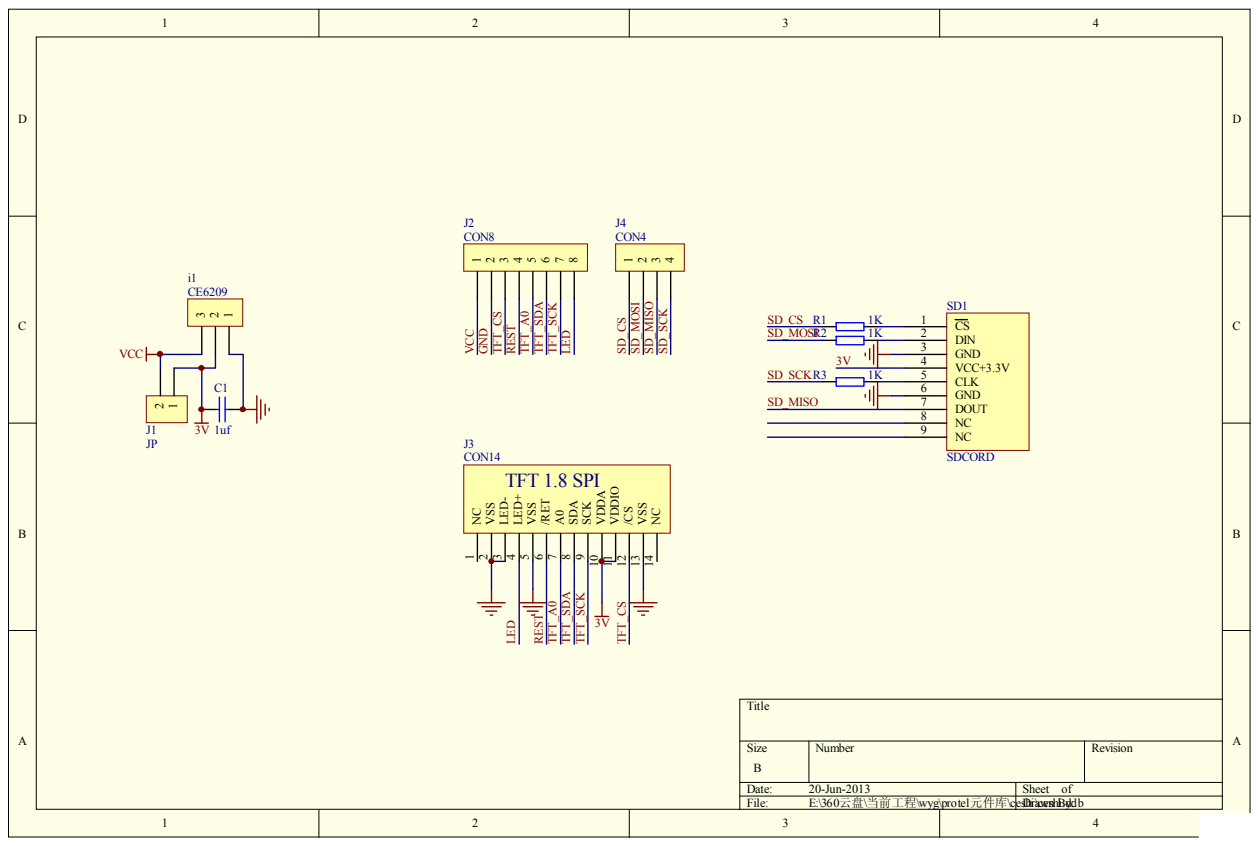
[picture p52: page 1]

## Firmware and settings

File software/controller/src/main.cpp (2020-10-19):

/**
 * [Fat Bottomed Board] controller firmware
 * 
 * @author  Ben
 */

// System includes
#include <Arduino.h>
#include <SPI.h>
#include <SD.h>
#include <TFT.h>
#include <MD_REncoder.h>

// Project includes
#include "defines.h"
#include "display.h"
#include "data.h"
// Machine state pages
#include "stateMain.h"
#include "stateMenu.h"
#include "stateMacro.h"
#include "stateSetup.h"
#include "stateBacklight.h"
#include "gamepong.h"

// Project objects
TFT         
    display = TFT(LCD_CS, LCD_DC, LCD_RESET);                           // TFT display
File
    fileMacro;                                                          // MACRO.KEY file
MD_REncoder
    control = MD_REncoder(ENCODER_CONTROL_CLK, ENCODER_CONTROL_DT),     // [control] Rotary encoder
    macro   = MD_REncoder(ENCODER_MACRO_CLK,   ENCODER_MACRO_DT);       // [macro]   Rotary encoder
menuObject                                                              
    menu;                                                               // menu application widget
gaugeObject
    gauge;                                                              // gauge application widget
byte
    status,                                                             // State Machine status
    keyboardLeds,                                                       // Current keyboard leds status
    ledMode, ledLight,                                                  // Backlight leds (Light Mode, Light intensity)
    AudioVolume,                                                        // Current audio volume (percentage)
    screenSaver,                                                        // Screen inactivity timeout (1 x 10s)
    controlScroll;                                                      // Lines to scroll
unsigned long                                                           // UL? a total waste of space but millis() might use that
    delayScrollArrow,                                                   // Scroll arrow delay on screen (ms) on main scroll
    delayKeyboardStatus,                                                // Delay led status detect (num, caps)
    inactivity;                                                         // Inactivity time, used in conjunction with [screenSaver]. 0:Screen turned off
char
    sCompose[3],                                                        // Current Keyboard : "UI", "IT", "EN"
    sOSType[10],                                                        // Current OS       : "Linux", "MacOS", "Windows"
    cmdBuffer[BUFFERMAX],
    cmdBuffer1[BUFFERTEENSY];


// Change state machine state
void stateSet(byte newStatus) {
    status = newStatus;
    switch (status) {
    case STATUS_NONE:
        mainPage();
        keyboardLeds = 0xFF;
        return;
    case STATUS_MENU:
        menuPage();
        return;
    case STATUS_SETUP:
        setupPage();
        return;
    case STATUS_BACKLIGHT:
        backlightPage();
        return;
    case STATUS_GAUGE:
        gauge.Show();
        return;
    case STATUS_MACRO:
        macroPage();
        return;
    case STATUS_REMOTECONFIG:
        displayRemoteConfigWaiting();
        return;
    case STATUS_GAME_PONG:
        gamepongPage();
    }
} /**/


// Return current status
byte stateGet() {
    return status;
} /**/


// Show controls or changing widgets in the current state
void stateLoop() {
    // Screensaver detection, turn off display when needed                      // ([screenSaver] * 10s)
    if ((millis()-inactivity)/1000 > screenSaver*10) {
        inactivity = 0;                                                         // inactivity is 0 when display is turned off
        displayLed(LOW);
    }
    // Screen is on
    if (inactivity > 0) {
        // Menus loop operations, if any
        switch (status) {
        case STATUS_NONE:
            mainLoop();                                                         // Main menu display (Num,Caps and scroll arrows)
            delay(5);                                                           // Some delay so the mouse doesn't move too fast
            break;
        case STATUS_GAME_PONG:
            gamepongLoop();
            break;
        }
    }
} /**/


// Detected action, tell program what to do
void stateAction(byte Action) {
    // Drop NULL actions
    if (Action==ACTION_NONE)
        return;
    // if I received some input and screen is now turned off I need to turn it on again
    if (inactivity==0) {
        displayLed(HIGH);
    }
    inactivity = millis();
    // Now detect proper action
    switch (status) {
    case STATUS_NONE:
        mainAction(Action);
        break;
    case STATUS_MENU:
        menuAction(Action);
        break;
    case STATUS_SETUP:
        setupAction(Action);
        break;
    case STATUS_BACKLIGHT:
        backlightAction(Action);
        break;
    case STATUS_GAUGE:
        gauge.action(Action);
        break;
    case STATUS_MACRO:
        macroAction(Action);
        break;
    case STATUS_GAME_PONG:
        gamepongAction(Action);
        break;
    }
} /**/


/**
 * LED MODE SET - Setup led backlight (based on [ledMode] and [ledLight])
 */
void ledModeSet() {
    // General backlight leds
    switch (ledMode) {
    case LED_MODE_ON:
    case LED_MODE_ON_MORELIGHT:
    case LED_MODE_REVERSE:
        analogWrite(PIN_LED_GENERAL, ledLight);
        break;    
    default:
        analogWrite(PIN_LED_GENERAL, 0);
        break;
    }
} /**/


/**
 * @see Internally used by [ledCapsLockSet] [ledNumLockSet]
 */
void ledServiceSet(byte Active, byte LedPin) {
    switch (ledMode) {
    case LED_MODE_OFF:
        analogWrite(LedPin, 0);
        return;
    case LED_MODE_ON:
        analogWrite(LedPin, ledLight);
        return;
    case LED_MODE_ON_MORELIGHT:
        if (Active == LOW) {
            analogWrite(LedPin, ledLight);
        } else {
            analogWrite(LedPin, ledLight*2);
        }
        return;
    case LED_MODE_NORMAL:
        if (Active == LOW) {
            analogWrite(LedPin, 0);
        } else {
            analogWrite(LedPin, ledLight);
        }
        return;
    case LED_MODE_REVERSE:
        if (Active == LOW) {
            analogWrite(LedPin, ledLight);
        } else {
            analogWrite(LedPin, 0);
        }
        return;
    }
} /**/


/**
 * SET CAPS LOCK - Set capslock light
 */
void ledCapsLockSet(byte Active) {
    ledServiceSet(Active, PIN_LED_CAPS_LOCK);
} /**/


/**
 * SET NUM LOCK - Set numlock light
 */
void ledNumLockSet(byte Active) {
    ledServiceSet(Active, PIN_LED_NUM_LOCK);
} /**/


/**
 * Set required layout (on TFT display)
 */
void layout(const char *Layout) {
    displayTurnOn();
    memcpy(sCompose, Layout, 2);
    sCompose[2] = 0x00;
    mainCompose();
} /**/


/**
 * Show current OS (just a label sent from qmk fw)
 */
void osType(char *osType) {
    displayTurnOn();
    // memcpy(sOSType, osType, strlen(osType));
    // sOSType[strlen(osType)] = 0x00;
    display.fillRect(0, 0, 55, 10, 0x0000);
    display.setTextSize(1);
    display.stroke(255, 255, 255);
    display.setCursor(1, 1);
    // display.print(sOSType);
    display.print(osType);
} /**/


// Init
void setup() {
    // TFT init
    pinMode(LCD_LED, OUTPUT);                       // Set LCD_LED as output
    delay(500);
    displayLed(HIGH);                               // Turn on lcd led display
    delay(500);
    display.begin();                                // TFT begin() more times ? yes, if you put it once it doesn't init the screen 
    delay(250);                                     // .... properly on boot. Do it more than once to properly boot on dry run
    display.begin();
    delay(250);
    delayKeyboardStatus =
    delayScrollArrow    = 0;
    inactivity = millis();
    Mouse.begin();                                  // HID Mouse setup, keyboard.begin is not needed
    cmdStart();
    Serial.begin(115200);                           // Serial HID (CDC) used for the keyboard setup from host
    // while (!Serial);                                // Wait for serial port to connect. Needed for native USB
    cmdInitTeensy();
    Serial1.begin(9600);
    // Encoders setup
    control.begin();
    macro.begin();
    pinMode(ENCODER_CONTROL_SW, INPUT_PULLUP);
    pinMode(ENCODER_MACRO_SW,   INPUT_PULLUP);
    // SD test (begin)
    if (!SD.begin(SD_CS)) {
        displayErrorMessage(F(" open failed"));
        while (1);
    }
    fileMacro = SD.open(FILE_MACRO, FILE_WRITE);
    if (!fileMacro) {
        displayErrorMessage(F("  MACRO.KEY"));
        while (1);
    }
    fileMacro.close();
    // Database readings
    controlScroll = configRead(DB_SCROLL_SIZE,  1);
    AudioVolume   = configRead(DB_AUDIO,        50);
    screenSaver   = configRead(DB_SCREEN_SAVER, 30);// Default: 5mins ([30] x 10s)
    ledMode       = configRead(DB_LED_MODE,     LED_MODE_NORMAL);
    ledLight      = configRead(DB_LED_LIGHT,    2);
    ledModeSet();
    // Menu
    memset(sCompose, 0x00, 3); memcpy_P(sCompose, F("EN"),     2);
    memset(sOSType,  0x00, 6); memcpy_P(sOSType,  F("Linux"),  5);
    stateSet(STATUS_NONE);
} /**/


// Main - loop
void loop() {
    // encoder [Control] movement
    switch (control.read()) {
        case DIR_CW:
            stateAction(ACTION_CONTROL_RIGHT);
            break;
        case DIR_CCW:
            stateAction(ACTION_CONTROL_LEFT);
            break;
    }
    // encoder [Control] button toggle
    if (digitalRead(ENCODER_CONTROL_SW) == LOW) {
        stateAction(ACTION_CONTROL_BUTTON);
    }

    // encoder [Macro] movement
    switch (macro.read()) {
        case DIR_CW:
            stateAction(ACTION_MACRO_RIGHT);
            break;
        case DIR_CCW:
            stateAction(ACTION_MACRO_LEFT);
            break;
    }
    // encoder [Macro] button toggle
    if (digitalRead(ENCODER_MACRO_SW) == LOW) {
        stateAction(ACTION_MACRO_BUTTON);
    }

    // Check if there some data from Host
    if (Serial.available() > 0) {
        cmdSerialRead();                        // read the incoming byte and process it [data.cpp]
    }
    // ...or from the other Teensy board
    if (Serial1.available() > 0) {
        cmdSerial1Read();
    }
    
    // State machine loop
    stateLoop();
} /**/

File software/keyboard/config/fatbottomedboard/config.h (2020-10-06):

/**
 * Copyright 2020 Ben
 * 
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
 */
#pragma once

#include "config_common.h"

/* USB Device descriptor parameter */
#define VENDOR_ID       0x08DE
#define PRODUCT_ID      0xC0DE
#define DEVICE_VER      0x0001
#define MANUFACTURER    Ben
#define PRODUCT         Fat Bottomed Keyboard
#define DESCRIPTION     Personal keyboard for daily usage

/* key matrix size */
#define MATRIX_ROWS     6
#define MATRIX_COLS     20

/*
 * Keyboard Matrix Assignments
 *
 * Change this to how you wired your keyboard
 * COLS: AVR pins used for columns, left to right
 * ROWS: AVR pins used for rows, top to bottom
 * DIODE_DIRECTION: COL2ROW = COL = Anode (+), ROW = Cathode (-, marked on diode)
 *                  ROW2COL = ROW = Anode (+), COL = Cathode (-, marked on diode)
 *
 */     /* key matrix pins */
#define MATRIX_ROW_PINS { C2, C3, C4, C5, C6, C7 }
#define MATRIX_COL_PINS { F2, F1, F0, E6, E7, B0, B1, B2, B3, B4, B5, B6, B7, D4, D5, D7, E0, E1, C0, C1 }
#define UNUSED_PINS

/* COL2ROW, ROW2COL*/
#define DIODE_DIRECTION COL2ROW


/*
 * Split Keyboard specific options, make sure you have 'SPLIT_KEYBOARD = yes' in your rules.mk, and define SOFT_SERIAL_PIN.
 */
//#define SOFT_SERIAL_PIN E6  // or D1, D2, D3, E6

// #define BACKLIGHT_PIN B7
// #define BACKLIGHT_BREATHING
// #define BACKLIGHT_LEVELS 3



// #define RGB_DI_PIN E2
// #ifdef RGB_DI_PIN
//   #define RGBLED_NUM 16
//   #define RGBLIGHT_HUE_STEP 8
//   #define RGBLIGHT_SAT_STEP 8
//   #define RGBLIGHT_VAL_STEP 8
//   #define RGBLIGHT_LIMIT_VAL 255 /* The maximum brightness level */
//   #define RGBLIGHT_SLEEP  /* If defined, the RGB lighting will be switched off when the host goes to sleep */
// /*== all animations enable ==*/
//   #define RGBLIGHT_ANIMATIONS
// /*== or choose animations ==*/
//   #define RGBLIGHT_EFFECT_BREATHING
//   #define RGBLIGHT_EFFECT_RAINBOW_MOOD
//   #define RGBLIGHT_EFFECT_RAINBOW_SWIRL
//   #define RGBLIGHT_EFFECT_SNAKE
//   #define RGBLIGHT_EFFECT_KNIGHT
//   #define RGBLIGHT_EFFECT_CHRISTMAS
//   #define RGBLIGHT_EFFECT_STATIC_GRADIENT
//   #define RGBLIGHT_EFFECT_RGB_TEST
//   #define RGBLIGHT_EFFECT_ALTERNATING
// /*== customize breathing effect ==*/
//   /*==== (DEFAULT) use fixed table instead of exp() and sin() ====*/
//   #define RGBLIGHT_BREATHE_TABLE_SIZE 256      // 256(default) or 128 or 64
//   /*==== use exp() and sin() ====*/
//   #define RGBLIGHT_EFFECT_BREATHE_CENTER 1.85  // 1 to 2.7
//   #define RGBLIGHT_EFFECT_BREATHE_MAX    255   // 0 to 255
// #endif

/* Debounce reduces chatter (unintended double-presses) - set 0 if debouncing is not needed */
#define DEBOUNCE 5

/* define if matrix has ghost (lacks anti-ghosting diodes) */
//#define MATRIX_HAS_GHOST

/* Mechanical locking support. Use KC_LCAP, KC_LNUM or KC_LSCR instead in keymap */
//#define LOCKING_SUPPORT_ENABLE
/* Locking resynchronize hack */
//#define LOCKING_RESYNC_ENABLE

/* If defined, GRAVE_ESC will always act as ESC when CTRL is held.
 * This is userful for the Windows task manager shortcut (ctrl+shift+esc).
 */
// #define GRAVE_ESC_CTRL_OVERRIDE

/*
 * Force NKRO
 *
 * Force NKRO (nKey Rollover) to be enabled by default, regardless of the saved
 * state in the bootmagic EEPROM settings. (Note that NKRO must be enabled in the
 * makefile for this to work.)
 *
 * If forced on, NKRO can be disabled via magic key (default = LShift+RShift+N)
 * until the next keyboard reset.
 *
 * NKRO may prevent your keystrokes from being detected in the BIOS, but it is
 * fully operational during normal computer usage.
 *
 * For a less heavy-handed approach, enable NKRO via magic key (LShift+RShift+N)
 * or via bootmagic (hold SPACE+N while plugging in the keyboard). Once set by
 * bootmagic, NKRO mode will always be enabled until it is toggled again during a
 * power-up.
 *
 */
//#define FORCE_NKRO

/*
 * Magic Key Options
 *
 * Magic keys are hotkey commands that allow control over firmware functions of
 * the keyboard. They are best used in combination with the HID Listen program,
 * found here: https://www.pjrc.com/teensy/hid_listen.html
 *
 * The options below allow the magic key functionality to be changed. This is
 * useful if your keyboard/keypad is missing keys and you want magic key support.
 *
 */

/* key combination for magic key command */
/* defined by default; to change, uncomment and set to the combination you want */
// #define IS_COMMAND() (get_mods() == MOD_MASK_SHIFT)

/* control how magic key switches layers */
//#define MAGIC_KEY_SWITCH_LAYER_WITH_FKEYS  true
//#define MAGIC_KEY_SWITCH_LAYER_WITH_NKEYS  true
//#define MAGIC_KEY_SWITCH_LAYER_WITH_CUSTOM false
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

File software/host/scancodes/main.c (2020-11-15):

/* Name: main.c
 * Project: hid-data, example how to use HID for data transfer
 * Author: Christian Starkjohann
 * Creation Date: 2008-04-11
 * Tabsize: 4
 * Copyright: (c) 2008 by OBJECTIVE DEVELOPMENT Software GmbH
 * License: GNU GPL v2 (see License.txt), GNU GPL v3 or proprietary (CommercialLicense.txt)
 */

/*
This example should run on most AVRs with only little changes. No special
hardware resources except INT0 are used. You may have to change usbconfig.h for
different I/O pins for USB. Please note that USB D+ must be the INT0 pin, or
at least be connected to INT0 as well.
*/

#include <avr/io.h>
#include <avr/wdt.h>
#include <avr/interrupt.h>  /* for sei() */
#include <util/delay.h>     /* for _delay_ms() */
#include <avr/eeprom.h>

#include <avr/pgmspace.h>   /* required by usbdrv.h */
#include "usbdrv.h"
#include "oddebug.h"        /* This is also an example for using debug macros */


#include <main.h>
#include <general.h>
#include <string.h>

#define BUFFER_LEN 50                           // Keyboard buffer length
unsigned char KeyboardBuffer[BUFFER_LEN];       // Keyboard buffer

uchar   uCode;                                  // Scancode read from SUN keyboard
uint8_t KeyboardCurrentKey;                     // Current scancode to output
uint8_t KeyboardSize;                           // Current occupied size in the keyboard buffer


/* ------------------------------------------------------------------------- */
/* ----------------------------- USB interface ----------------------------- */
/* ------------------------------------------------------------------------- */

PROGMEM const char usbHidReportDescriptor[22] = {    /* USB report descriptor */
    0x06, 0x00, 0xff,              // USAGE_PAGE (Generic Desktop)
    0x09, 0x01,                    // USAGE (Vendor Usage 1)
    0xa1, 0x01,                    // COLLECTION (Application)
    0x15, 0x00,                    //   LOGICAL_MINIMUM (0)
    0x26, 0xff, 0x00,              //   LOGICAL_MAXIMUM (255)
    0x75, 0x08,                    //   REPORT_SIZE (8)
    0x95, 0x80,                    //   REPORT_COUNT (128)
    0x09, 0x00,                    //   USAGE (Undefined)
    0xb2, 0x02, 0x01,              //   FEATURE (Data,Var,Abs,Buf)
    0xc0                           // END_COLLECTION
};
/* Since we define only one feature report, we don't use report-IDs (which
 * would be the first byte of the report). The entire report consists of 128
 * opaque data bytes.
 */

/* The following variables store the status of the current data transfer */
static uchar    currentAddress;
static uchar    bytesRemaining;

/* ------------------------------------------------------------------------- */
/**
 * KEYBOARD RESET BUFFER - Reset the keyboard buffer
 */
void KeyboardResetBuffer() {
    memset(KeyboardBuffer, 0x00, BUFFER_LEN);
    KeyboardCurrentKey = KeyboardSize = 0;
} /**/


/* usbFunctionRead() is called when the host requests a chunk of data from
 * the device. For more information see the documentation in usbdrv/usbdrv.h.
 */
uchar   usbFunctionRead(uchar *data, uchar len) {
    uint8_t i;
    if(len > bytesRemaining)
        len = bytesRemaining;
//    eeprom_read_block(data, (uchar *)0 + currentAddress, len);
    memset(data, 0x00, len);

    for (i=0; i<len; i++) {
        if (KeyboardCurrentKey < KeyboardSize) {
            *(data+i) = KeyboardBuffer[KeyboardCurrentKey++];
        } else {
            *(data+i) = 0x00;
//            *(data+i) = usbHidReportDescriptor[15];
        }
    }
    bytesRemaining -= len;

    if (bytesRemaining <= 0) {
        KeyboardResetBuffer();
    }

    return len;
}


/* usbFunctionWrite() is called when the host sends a chunk of data to the
 * device. For more information see the documentation in usbdrv/usbdrv.h.
 */
uchar   usbFunctionWrite(uchar *data, uchar len)
{
    if(bytesRemaining == 0)
        return 1;               /* end of transfer */
    if(len > bytesRemaining)
        len = bytesRemaining;
    eeprom_write_block(data, (uchar *)0 + currentAddress, len);
    currentAddress += len;
    bytesRemaining -= len;
    return bytesRemaining == 0; /* return 1 if this was the last chunk */
}

/* ------------------------------------------------------------------------- */

usbMsgLen_t usbFunctionSetup(uchar data[8]) {
    usbRequest_t    *rq = (void *)data;

    if((rq->bmRequestType & USBRQ_TYPE_MASK) == USBRQ_TYPE_CLASS){    /* HID class request */
        if(rq->bRequest == USBRQ_HID_GET_REPORT){  /* wValue: ReportType (highbyte), ReportID (lowbyte) */
            /* since we have only one report type, we can ignore the report-ID */
            bytesRemaining = 128;
            currentAddress = 0;
            return USB_NO_MSG;  /* use usbFunctionRead() to obtain data */
        }else if(rq->bRequest == USBRQ_HID_SET_REPORT){
            /* since we have only one report type, we can ignore the report-ID */
            bytesRemaining = 128;
            currentAddress = 0;
            return USB_NO_MSG;  /* use usbFunctionWrite() to receive data from host */
        }
    }else{
        /* ignore vendor type requests, we don't use any */
    }
    return 0;
}


/**
 * HARDWARE INIT - General initialization stuff for the board
 */
void HardwareInit() {
    // I/O Ports
    DDRC |= (1<< (IO_PORT_C ^ IO_PORT_C5) );    // Set IO_PORT_C5 in output mode
    SerialInit();                               // Com port setup

    KeyboardResetBuffer();                      // Reset the keyboard buffer

    // All done, system ready
    LedOn();
}

/* ------------------------------------------------------------------------- */

int main(void) {
    uchar   i;

    // HW and serial init
    HardwareInit();

    wdt_enable(WDTO_1S);
    /* Even if you don't use the watchdog, turn it off here. On newer devices,
     * the status of the watchdog (on/off, period) is PRESERVED OVER RESET!
     */
    /* RESET status: all port bits are inputs without pull-up.
     * That's the way we need D+ and D-. Therefore we don't need any
     * additional hardware initialization.
     */
    odDebugInit();
    DBG1(0x00, 0, 0);       /* debug output: main starts */
    usbInit();
    usbDeviceDisconnect();  /* enforce re-enumeration, do this while interrupts are disabled! */
    i = 0;
    while(--i){             /* fake USB disconnect for > 250 ms */
        wdt_reset();
        _delay_ms(1);
    }
    usbDeviceConnect();
    sei();
    DBG1(0x01, 0, 0);       /* debug output: main loop starts */
    for(;;){                /* main event loop */
        DBG1(0x02, 0, 0);   /* debug output: main loop iterates */
        wdt_reset();
        usbPoll();
    }
    return 0;
}


/**
 * Interrupt driven function for dealing serial RX data flow
 */
ISR(USART_RX_vect) {
    KeyboardBuffer[KeyboardSize++] = UDR0;
}

/* ------------------------------------------------------------------------- */

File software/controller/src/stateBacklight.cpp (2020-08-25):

#include "stateBacklight.h"
extern menuObject   menu;
extern gaugeObject  gauge;
extern byte         ledMode;
extern byte         ledLight;
extern byte         keyboardLeds;


/**
 * display page title and menu
 */
void backlightPage() {
    menuInit(F("BACKLIGHT"), 25, backlightShow);
} /**/


/**
 * display setup menu, right after [setupPage]
 */
void backlightShow() {
    char text[30];
    switch (ledMode) {
    case LED_MODE_OFF:
        menu.itemShow(F("Mode:          Always OFF"));
        break;
    case LED_MODE_NORMAL:
        menu.itemShow(F("Mode:            Standard"));
        break;
    case LED_MODE_ON:
        menu.itemShow(F("Mode:           Always ON"));
        break;
    case LED_MODE_ON_MORELIGHT:
        menu.itemShow(F("Mode:     ON + Light Diff"));
        break;
    case LED_MODE_REVERSE:
        menu.itemShow( F("Mode:            Reversed"));
        break;
    }
    sprintf_P(text, PSTR("LED Brightness       [%2d]"), ledLight);
    menu.itemShowStr(text);
    menu.itemShow(F("EXIT"));
} /**/


void backlightAction(byte Action) {
    switch (Action) {
    case ACTION_CONTROL_LEFT:       // Control rotary encoder movement [UP]
        menu.moveUp();
        break;
    case ACTION_CONTROL_RIGHT:      // Control rotary encoder movement [DOWN]
        menu.moveDown();
        break;
    case ACTION_CONTROL_BUTTON:     // Control button press
        backlightSelect(menu.itemGet());
        break;
    }
} /**/


void backlightSelect(byte Choice) {
    switch (Choice) {
    case 0:                         // Change backlight mode
        ledMode = (ledMode==LED_MODE_REVERSE? 0: ledMode+1);
        configWrite(DB_LED_MODE, ledMode);
        menu.showMenu();
        ledModeSet();
        ledCapsLockSet(keyboardLeds & LED_CAPS_LOCK ? HIGH: LOW);
        ledNumLockSet(keyboardLeds  & LED_NUM_LOCK  ? HIGH: LOW);
        delay(500);
        break;
    case 1:                         // Change LED brightness
        gauge.handler(backlightControl);
        analogWrite(PIN_LED_GENERAL, ledLight);
        gauge.init(&ledLight, DB_LED_LIGHT, 0, 20, 1, F("brightness"), F("LED backlight intensity"));
        delay(500);
        ledModeSet();
        ledCapsLockSet(keyboardLeds & LED_CAPS_LOCK ? HIGH: LOW);
        ledNumLockSet(keyboardLeds  & LED_NUM_LOCK  ? HIGH: LOW);
        break;
    default:                        // Return to default state
        stateSet(STATUS_MENU);
    }
} /**/


/**
 * VOLUME CONTROL - Volume control with rotary encoder (because everyone love knobs !)
 */
void backlightControl(byte Action) {
    switch (Action) {
    case GAUGE_UP:
    case GAUGE_DOWN:
        analogWrite(PIN_LED_GENERAL, gauge.Value());
        break;
    }
} /**/

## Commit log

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2019-02-22 updated layout with big plus sign on numpad
    [keyboard-frame.dxf]
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2020-04-24 Added second rotary encoder
    [32U4.sch]
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2020-04-25 Added SD Card for password manager
    [32U4.sch]
2020-04-27 SD Card added, 16U4 Labels added
    [32U4.sch]
2020-05-05 Moving controller to Teensy++ 2.0
    [Controller.sch]
2020-05-05 Teensy++ 2.0 circuit rewrite
    [Controller.sch]
2020-05-07 circuit rewritten for Teensy++ 2.0
    [Controller.sch]
2020-05-12 Minor fixes with two encoders and a display
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2020-06-27 COLS redraw to shorten wires
    [Keyboard.sch]
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2020-07-02 Updated config
    wrong wiring, fixed
2020-07-11 Added serial port communication
    Both ICs might exchange data through Serial1 port
    [Controller.sch, Keyboard.sch]
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2020-08-08 Added PWM LED control
    [Controller.sch]
2020-08-09 IRF 520 Power for keybd backlight
    [Controller.sch]
2020-08-10 Using PVM outputs for backlight leds
    [Controller.sch]
2020-08-11 Num&Caps control with LEDs
    [Controller.sch]
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2020-08-11 Backlight modes and configuration menu
    [Controller.sch]
2020-08-12 num,caps,generic leds bugfix
    [Controller.sch]
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2020-08-20 new backlight schematic (darlington TIP112)
    [Controller.sch]
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2025-07-13 Mouse palm wrest protection
    [bam-Palm Left.stl, bam-Palm Right.stl, bam-Palm connection.stl]
2025-07-13 Thumb base for the mouse
    [bam-Thumb.stl]
2025-07-13 4,5 fingers mouse base
    [bam-palm-fingers.stl]
2025-07-13 Adding fingers base plate
    [bam-Left and Right.stl, bam-Right.stl, bam-all fingers.stl]
2025-07-16 mouse needle. The only contact point to the surface
    [bam-desk needle.stl]
2025-07-17 Bottom part of the mouse
    [bam-palm-thumb.stl]
2025-07-18 Connection between thumb and left/right mouse buttons finger
    [bam-left,right - thumb.stl]
2025-07-26 Making space for the PCB
    [bam-Left and Right.stl]
2025-07-26 Removing previous frame for a pcb holder
    [bam-all fingers.stl, bam-left,right - thumb.stl, bam-palm-fingers.stl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]
2025-07-26 New pcb holder and frame connector
    [bam-pcb holder.stl]
2025-07-26 Adding 1mm to this spacer
    [bam-desk needle.stl]
2025-07-26 improved pcb top base holder
    [bam-Left and Right.stl]
2025-07-28 cleaning up old files and creating new pcb holder
    [bam-Right.stl]
2025-07-29 Shaping it better for the top bottom part of the mouse
    [bam-Left and Right.stl]
2025-07-29 Enlarging needle for a manual self-snap on the base
    [bam-desk needle.stl]
2025-07-29 Shaping ring and pinky fingers bottom base
    [bam-Ring and Pinky.stl]
2025-07-30 Reshaping palm connection, Simplifying layout
    [bam-Palm connection.stl]
2025-07-30 reshaping top and left side, removing left border
    [bam-pcb holder.stl]
2025-07-30 Scroll wheel lock, connected to left/right base too
    [bam-wheel lock.stl]
2025-07-31 Adding bridge for the pinky finger
    [bam-bridge pinky.stl]
2025-08-01 Adding 3d button on the thumb
    [bam-support 3rd button.stl]
2025-08-01 Adding base for the 3rd button frame
    [bam-base support 3rd button.stl]
2025-08-02 Adding third mouse buttom, usable from the thumb
    [bam-3rd button.stl]
2025-08-03 Cleaning old 3d button support, creating a new one
    [bam-base support 3rd button.stl, bam-support 3rd button.stl]
2025-08-03 Making space for wheel support bracket
    [bam-wheel lock.stl]
2025-08-04 Moving 3rd button 5mm backward
    [bam-3rd button.stl]
2025-08-04 Creating pinky bridge as outer right struct to the chassis
    [bam-bridge pinky.stl]
2025-08-04 Lowering the pinky bridge to better fit the shape of my hand
    [bam-bridge pinky.stl]
2025-08-04 Reshaping left bridge to fit the new button
    [bam-bridge left.stl]
2025-08-04 re-engineering the new support to rely on the left bridge only
    [bam-support 3rd button.stl]
2025-08-06 Adding holes for partition junctions
    [bam-bridge right.stl]
2025-08-06 Adding first partition for keeping pink and ring fingers in place
    [bam-partition pinky right 1.stl]
2025-08-07 Adding second partition support for ring and pinky fingers
    [bam-partition pinky right 2.stl]
2025-08-08 Adding back partition connection for the palm
    [bam-partition back.stl]
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2025-08-10 unite partitions from left to right to pinky finger
    [bam-partition pinky right 2.stl]
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2025-08-12 Adding scroll wheel+pcb holder on the back, Logi's default is not that good
    [bam-scroll wheel holder.stl]
2025-08-13 Enhanced wheel holder, lowered for infinity scroll proper management
    [bam-scroll wheel holder.stl]
2025-08-13 Free wires internal cable holder (#2 of them)
    [bam-cable holder.stl]
2025-08-14 Smoothing rough edges around right bridge, Hiding mounting holes
    [bam-partition pinky right 2.stl]
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2025-08-17 Adding base mouse buttons handler to bottom left/right partition holder
    [bam-mouse buttons.stl]
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2025-08-23 Reshaping buttons and making them concave to better follow fingers movement
    [bam-mouse buttons.stl]
2025-08-23 Reducing the desk surface with a cone to 0.6mm
    [bam-desk needle.stl]
2025-08-23 Adding small support for raising ring finger above the surface
    [bam-Ring holder.stl]
2025-08-24 Shortening mouse buttons, adding strength to buttons base
    [bam-mouse buttons.stl]
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2025-08-28 Separator between ring and pinky, snap it to customize its behavior
    [bam-Ring holder top.stl]
2025-08-28 small thickness placed in between the button and the switch for precision clicks
    [bam-mouse button thickness.stl]
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2025-09-25 Adding handles for dealing with bottom bar reinforcement
    [bam-partition pinky right 2.stl]
2025-09-26 Adding underbridge pillar to reinforce skeleton structure
    [bam-underbridge blocker.stl]

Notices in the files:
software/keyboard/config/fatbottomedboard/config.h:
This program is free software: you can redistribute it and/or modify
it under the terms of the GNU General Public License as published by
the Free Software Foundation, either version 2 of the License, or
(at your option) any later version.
